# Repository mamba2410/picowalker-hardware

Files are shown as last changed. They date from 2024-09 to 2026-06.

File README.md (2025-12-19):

# picowalker hardware

This is the PCB hardware side of the [picowalker](https://github.com/mamba2410/picowalker) project.
The goal of the picowalker project is to create a new, modern equivalent to the Pokewalker distributed with the Pokemon HeartGold and SoulSilver games back in 2010.
Since those units are no longer sold and are getting harder and harder to obtain, creating a new version sounds like the easiest option. And the most fun.

The hardware is designed around the RP2350 chip. STM32U5 versions have been considered for longer battery life, but they're more expensive and I'm worried about availability (and the name "picowalker" wouldn't work!)

Software for this can be found in the [picowalker](https://github.com/mamba2410/picowalker/) and [picowalker-core](https://github.com/mamba2410/picowalker-core/) repos.

## Features

- RP2350A as the main microcontroller.
- 1.8" AMOLED screen DO0180FMST03, 448x368 resolution (running at 384x256 for 4x upscaling) driven by PIO'd QSPI (output only).
- Rechargeable lithum battery via USB-C using the BQ25628E PMIC.
- Larger form factor to accommodate larger screen and battery.
- Custom shell based on the original Pokewalker designed by Kamp.
- IrDA driven by PIO courtesy of Dmitry gr's PIO code.
- 64kB EEPROM using the M95512 chip (same as in the original walker).
- Code and extra image flash using 16MB W25Q128.
- Accelerometer with BMA400 (successor to the original Pokewalker's one).
- USB 1.1 connection for flexible communications.
- High accuracy, low power 32.768 kHz clock for more accurate timekeeping (100 PPM).

## Dependencies

- [KiCad](https://www.kicad.org/) V9.0+
- [KiKit](https://yaqwsx.github.io/KiKit/latest/installation/intro/) plugin to generate panels.
- Symbols, footprints and models are either in KiCad standard library or in a project library.

## Current state (updated 2025-12-19)

V0.4 has passed DRC checks. Will go through a few reviews so expect some tweaks.
Hoping that this will be the final version and, once validated, will be uplifted to V1.0.

Here's a render of the board.

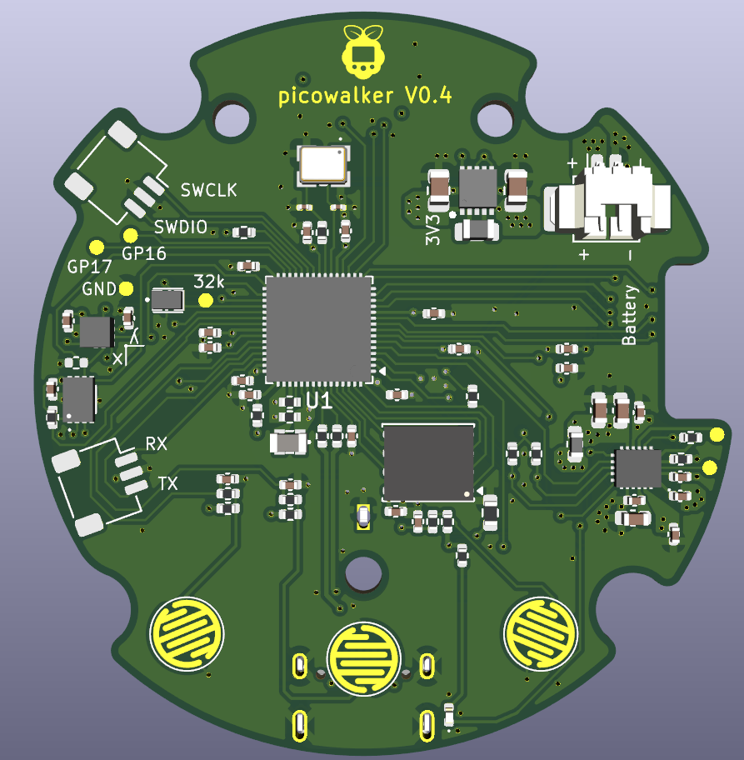
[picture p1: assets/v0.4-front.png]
front


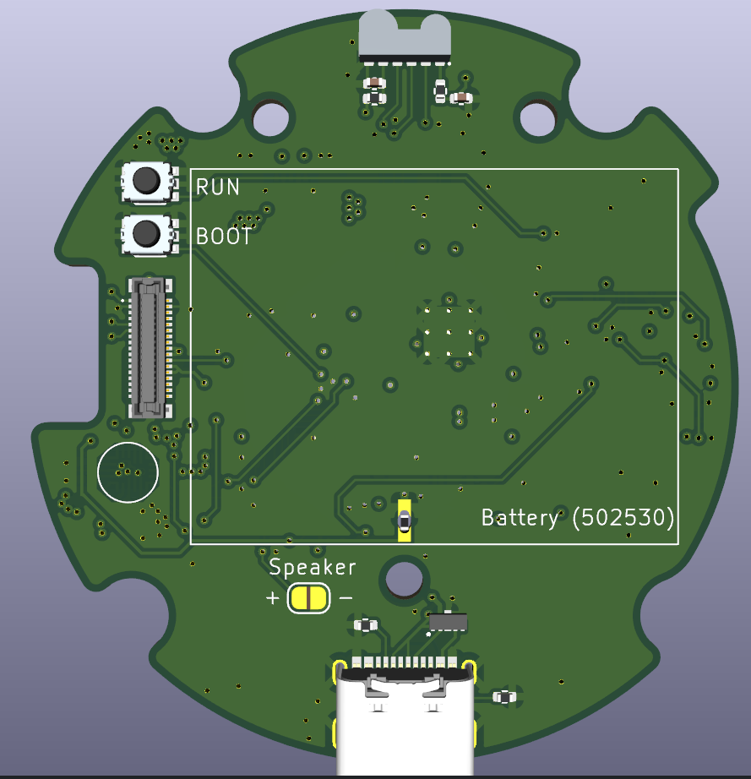
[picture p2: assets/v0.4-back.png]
back


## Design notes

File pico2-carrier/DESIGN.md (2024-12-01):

# Pico 2 Carrier board design

Already know that eeprom and accelerometer work.
Screen mostly works, but trying to eliminate interference by removing the jumper wires.

Heavily cutting unnecessary pins since we're very limited on the Pico 2 and preferably want to 
keep using the RP2350A version since the B version is physically much larger.

## Design goals

- Keep under the Pico 2 pin limit with minimal jumpers
- Separate battery and rest of board if charge circuit is bad
- Headers for screen in case the AXE534-127 connector is wired wrong
- Preferably 2-layer board but power management needs 4 layers
- Only single-sided components for ease of assembly

## Goals

On top of getting something working and broadly verifying 

- Generally verify schematics
- Get it portable
    - Reliable(?) step detection
- See if battery charging works
    - Needs lots of testing/verification (charge lim, values ok, EMI ok etc)
- Get screen more stable
- See if flash works
- See if PIO IrDA works
- Measure power consumption (from USB VBUS and battery/PMIC output)
    - Identify the most power-hungry things in the board
    - See how low rp2350 can go
    - See how low screen can go
- Check out power saving benefits
    - IrDA `IR_SD`
    - Screen `PWR_EN`
    - Putting things in sleep mode
    - Underclocking rp2350
- Identify pins that aren't strictly needed, so they can be cut in final version
    - `~{SCREEN_RST}` - software might be good enough
    - `~{BAT_CE}` - Software can disable charging even if this is asserted
    - `DBG_XX` - USB stdio works but these might be most useful
        (could disable transceiver and use IrDA pins as software-uart when not in connect mode)
- Using flash-as-eeprom
- Using pico as USB device

Things this WONT help out with

- Sound (had to cut that out because of pin space requirements)
- rp2350 power supply
- Converting VSYS to 3.3V
- Ditching separate flash for unified code/data flash
- USB-C connector, ESD protect and integration
- Fitting in form-factor/enclosure
    - And thermals

## Notes

### BQ25628E Battery charger PMIC

For the battery charging, The BQ25628E chip seems good and small enough to be used in the final version.
There is another chip in the line that's due to be out in the future that's smaller and cheaper 
but this one seems fine enough.

I'm trying to follow the reference design (what bits I can find in the datasheet) as closely as possible
since I'm not knowledgeable enough to deviate from it.
It might need a 4 layer board to have good grounding since there are a lot of crossing wires, especially
for the VBUS/VSYS and interface with the MCU.

### Passives

BQ25628E

- CVBUS 10V 1uF before derating
- CPMID 10V 10uF before derating
- CSYS 10V 20uF before derating
- CBAT 10V 10uF before derating
- LSW max 2.2uH
- CREGN 10V 4.7uF ceramic before derating
- CBTST 10B 47nF ceramic before derating
- Output capacitor 10V >=10uF ceramic X7R or X5R before derating
- Input capacitor (CPMID?) 25V 10uF ceramic X7R or X5R before derating

TFDU4101

- CVIRED rec. tantalum/fast rise 4.7uF/16V (assume before derating). Used as bulk/buffer
- CVCC rec. ceramic 0.1uF. Used in low-pass filter

M95512

- Decoupling capacitor between 10nF-100nF (assume before derating)

BMA400

- two decoupling capacitors 100nF (assume before derating)

W25Q128/IS25LP128

- No mention of capacitors

DO0180FMST08

- No mention of capacitors

## Datasheets and documentation

- Pico 2
    - [Pico 2 Datasheet](https://datasheets.raspberrypi.com/pico/pico-2-datasheet.pdf)
    - [RP2350 Datasheet](https://datasheets.raspberrypi.com/rp2350/rp2350-datasheet.pdf)
    - [RP2350 Hardware Design](https://datasheets.raspberrypi.com/rp2350/hardware-design-with-rp2350.pdf)
- M95512
    - [Datasheet](https://www.st.com/en/memories/m95512-w.html#documentation)
    - [Documentation](https://www.st.com/en/memories/m95512-w.html#documentation).
- BQ25628E
    - [Product Page](https://www.ti.com/product/BQ25628E)
    - [Datasheet](https://www.ti.com/lit/ds/symlink/bq25628e.pdf)
- W25Q128JV
    - [Product Page](https://www.winbond.com/hq/product/code-storage-flash-memory/serial-nor-flash/?__locale=en&partNo=W25Q128JV)
    - [Datasheet](https://www.mouser.com/datasheet/2/949/w25q128jv_revf_03272018_plus-1489608.pdf)
- BMA400
    - [Product Page](https://www.bosch-sensortec.com/products/motion-sensors/accelerometers/bma400/)
    - [Datasheet](https://www.bosch-sensortec.com/media/boschsensortec/downloads/datasheets/bst-bma400-ds000.pdf)
- TFDU4101
    - [Product Page](https://www.vishay.com/en/product/81288/)
    - [Datasheet](https://www.vishay.com/docs/81288/tfdu4101.pdf)
- DO0180FMST03
    - [Product Page (Module)](https://www.dwo.net.cn/pd.jsp?id=11924#_jcp=3_38)
    - [Product Page (Panel)](https://www.dwo.net.cn/pd.jsp?fromColId=2&id=11921#_pp=2_322)
    - [Module Datasheet](https://18746902.s21i.faimallusr.com/61/1/ABUIABA9GAAgivThrgYols7tsgE.pdf)
    - [Panel Datasheet](https://18746902.s21i.faimallusr.com/61/1/ABUIABA9GAAgm-3hrgYoq5PDogM.pdf)
    - [Driver Datasheet](https://18746902.s21i.faimallusr.com/61/1/ABUIABA9GAAgzvThrgYo8pyQBw.pdf)
    - [Touch Datasheet](https://18746902.s21i.faimallusr.com/61/1/ABUIABA9GAAg0-ThrgYosMjsrAY.pdf)

## Review

### EEPROM

According to ST's application note AN2014, the M95512 needs a (10k) pull-up on
the CSB line and strongly recommends a (100k) pull-down on the SCK line.
This then forces the SPI bus to be run in SPI mode 0.
It also strongly recommends a 100k pull-down on the D line (MOSI).
[Documentation](https://www.st.com/en/memories/m95512-w.html#documentation).

### PMIC

The PFET seemed to not work when OR'ing into the power circuit.
Removing it, then removing the Schottky diode on the pico, and shorting the
source and drain got the battery charging and power path to work.
Probably got the electrical design wrong since the pinouts seem correct.
But looking at the hardware design in the pico 2 datasheet, I have it correct.
Maybe the pull-down on VBUS is what's causing the PFET to work wrongly.

The SYS and PG signals seem to work well enough as LEDs.
Maybe don't need the PG signal, so can leave it floating, but no reason not to
have both.
No need to have them routed to the MCU since can read the status over I2C.

Battery charging works after the PFET situation was resolved.
Power-path also works.

ADC works, as well as interrupts, which is great.

### Flash

Haven't tested the flash, but that apparently also needs a 10k external pull-up
on the CS pin since that needs to follow VCC on power-up.

### IrDA

After some testing, the IR works well on PIO. Very glad I noticed the footprint
needed flipping since that was correct.
PIO needs to run quickly, works when clocked by 150MHz sys PLL, though not much
room for debug printing in between.

The current-limiting resistor hasn't seemed to have blown yet so I think it
seems to be fine with the power dissipation but should be a bit more careful.

Haven't tested the shutdown yet.

### Screen

The screen just works with the shorter traces, even running at 4x scale and
running from the 48MHz USB PLL.
Haven't tested max brightness yet but its probably similar to when on the
breadboard - can't run at panel max.
Screen flickers a lot less at 48MHz but that's the core code which needs to
manage it properly.
Also means that the connector is the correct polarity.

### Accel

Again, it just worked when porting the code over.
Polling for steps worked.
Some testing with interrupts and you can change the polarity and phase of the
interrupts.
Not gotten it to trigger yet, needs some more testing, but int is not really
needed.

### Power saving

Quick testing on the joulescope shows that there's some weirdness with going to
sleep.
First sleep from boot goes down to about 5mA, then subsequent sleeps go to 2mA.
1mA of the second was from the 3.3V rail, the rest was probably from the pico 2.
Good start, but not good enough.
This was without proper CS pull-ups on the flash chip.

Lots more testing to do:

- RP2350-E9
- Screen power saving

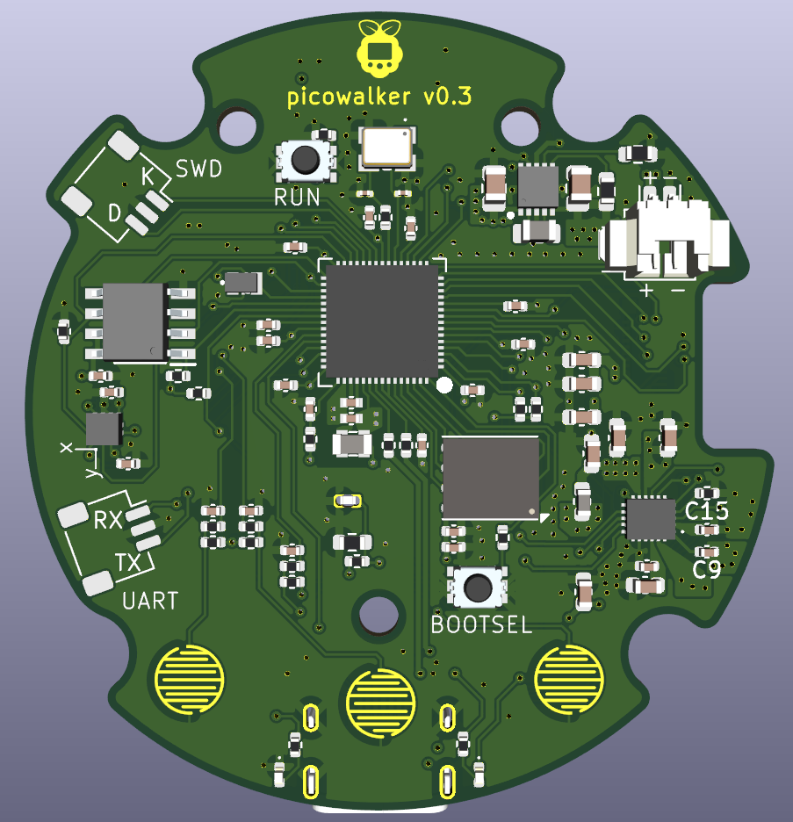
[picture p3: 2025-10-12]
assets/v0.3-front.png

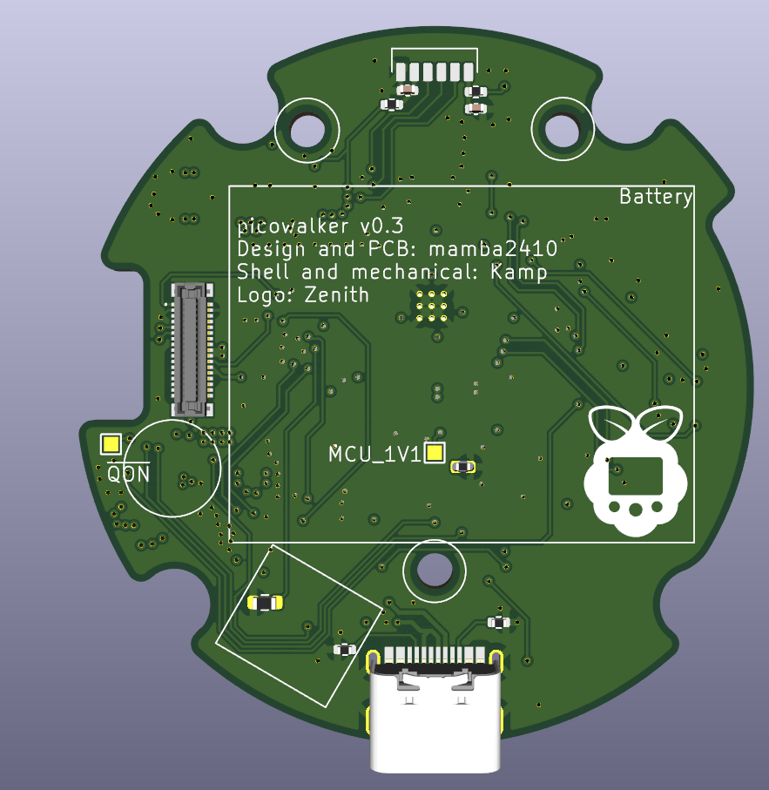
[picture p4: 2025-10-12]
assets/v0.3-back.png

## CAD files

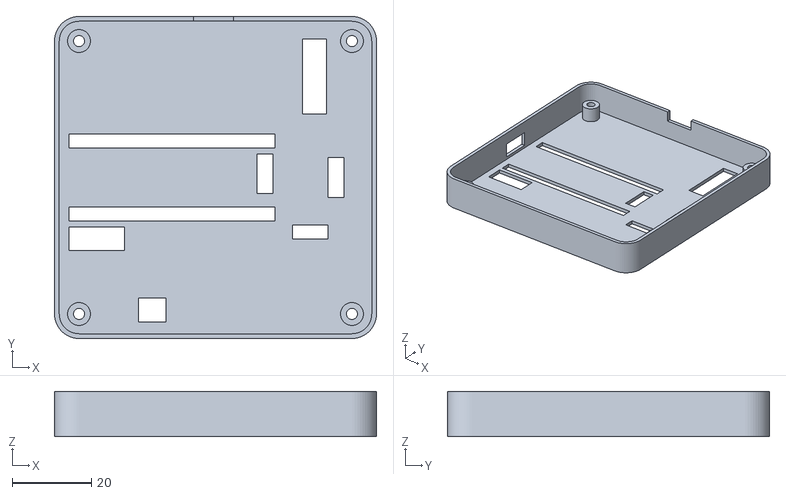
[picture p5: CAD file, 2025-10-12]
pico2-carrier/enclosure/shell-v0.0.1-bottom v12.stl
81.4 x 81.4 x 11.4

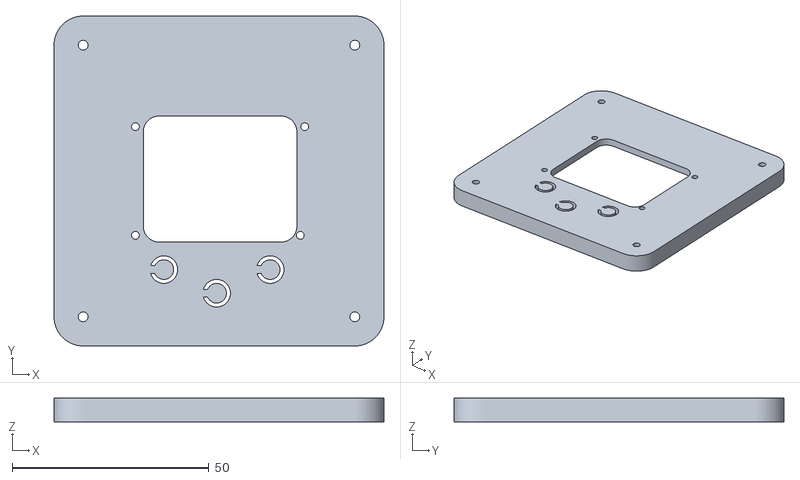
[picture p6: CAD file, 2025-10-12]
pico2-carrier/enclosure/shell-v0.0.1-top v5.stl
83.8 x 83.8 x 6.00

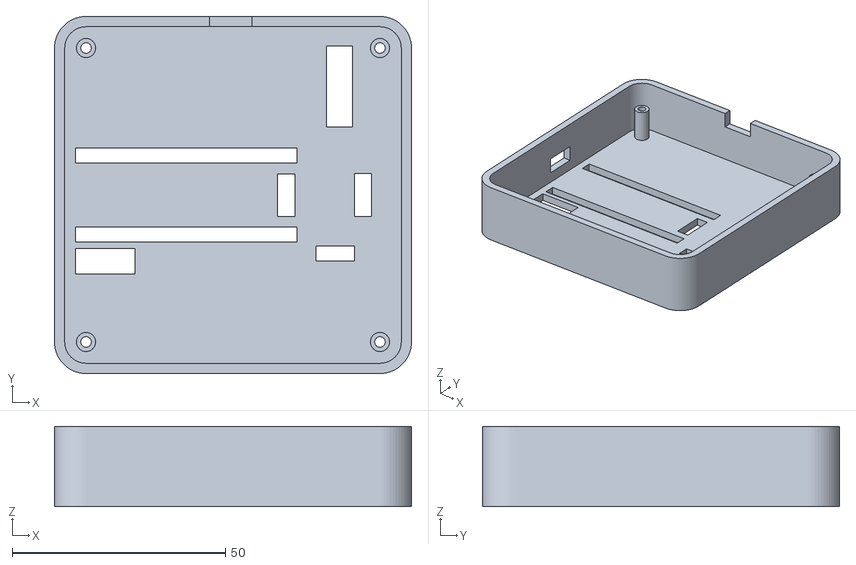
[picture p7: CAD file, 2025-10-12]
pico2-carrier/enclosure/shell-v0.0.1-bottom v4.stl
83.8 x 83.8 x 18.8

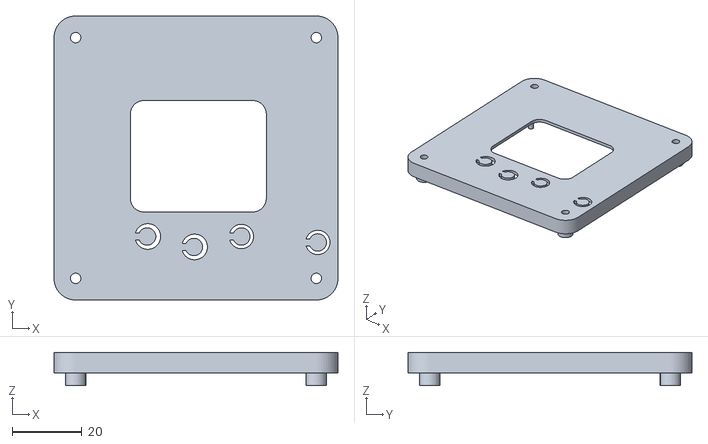
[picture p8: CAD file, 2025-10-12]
pico2-carrier/enclosure/shell-v0.0.1-top v12.stl
81.4 x 81.4 x 9.60

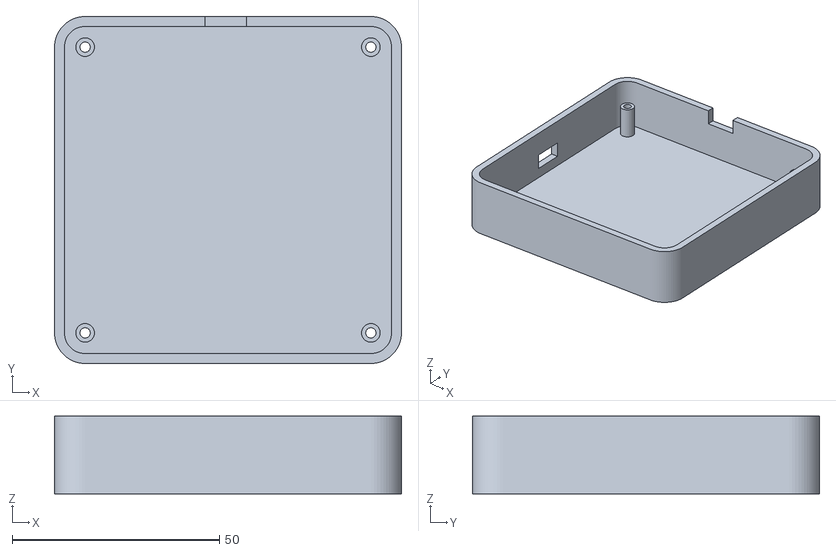
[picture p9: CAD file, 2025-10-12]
pico2-carrier/enclosure/shell-v0.0.1 v4.stl
83.8 x 83.8 x 18.8

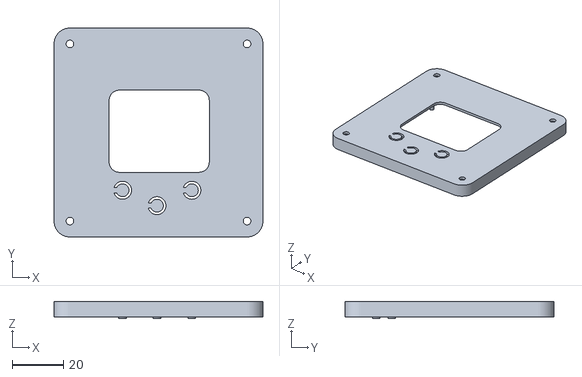
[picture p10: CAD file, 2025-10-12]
pico2-carrier/enclosure/shell-v0.0.1-top v7.stl
81.4 x 81.4 x 6.70

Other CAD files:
pico2-carrier/enclosure/shell-v0.0.1-bottom v7.stl
pico2-carrier/enclosure/shell-v0.0.1-bottom v8.stl
pico2-carrier/enclosure/shell-v0.0.1-top v4.stl
pico2-carrier/enclosure/shell-v0.0.1-top v8.stl

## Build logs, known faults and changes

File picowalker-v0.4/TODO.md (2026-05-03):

# Things to do before sending to fab

## Design

- Extend MP pads for debug headers

## Ordering

```bash
kikit panelize -p kikit.json picowalker-v0.4.kicad_pcb output/panelized/picowalker-v0.4-panelized.kicad_pcb
```

- 1.0 mm board thickness
- ENIG

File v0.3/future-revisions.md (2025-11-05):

# Things to do in a future revision

- Consolidate pull-ups to be a single value e.g. 10k or 5.1k, maybe also set ILIM to 5.1k for one less value.

## Second build

- Change USB connector to Amphenol version
- Replace 10k with 5.1k on button debounces
- Remove 0.1u cap from flash
- Try single 4.7u caps on screen VBAT and VDDIO
- Replace I2C pullups with 5.1k
- Replace accel decouples with 4.7u
- Remove eeprom SCL pulldown
- Replace eeprom CSB pullup with 5.1k
- Replace eeprom decouple with 4.7u
- Freestyle IrDA VCC2 filter to be 4.7u cap feeding into 47R resistor, to fix filter and consolidate parts
- Replace R18 and R19 pullups with 0R resistors to see if they actually need to be limiting anything
- Replace ILIM with 5.1k
- Replace battery and VBUS decoupling with 4.7u
- Replace top half of thermistor divider with 5.1k, and bottom with 30k
- Replace PG pull with 5.1k
- Replace R1 on rp2350 input filter with either 22R or 47R, probably 47R.
    - Datasheet and hardware design guide doesn't say much on the values.
      "33R and 4.7u is adequate" is about all thye say, and that its noise sensitive.
      47R and 4.7u is probably fine.

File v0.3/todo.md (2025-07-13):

# Todo before sending off for fab

## Parts

- Double check size of button contacts (currently 5mm diameter)
    - Contacts are 4.3mm, can't be arsed to change it this rev.
    - D-pad is also 4.3mm, letters are 5.3mm.

## Layout

- Move USB connector further out because its too recessed in the shell.
    - Currently already getting complained at by DRC.

## Checks

- DRC and make sure no nets are crossed due to the Big Move (TM).
- Assign and check part numbers and that they are in stock on mouser/partsbox
- Panelise
```
kikit panelize -p v0.3-kikit.json .\v0.3.kicad_pcb outputs\panelized\v0.3-panelized.kicad_pcb
```
- Export to JLC

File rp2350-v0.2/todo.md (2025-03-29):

# Todo before sending off for fab

Estimated shipping and fab is 8 days, so send off before weds 2nd april at latest.

Checks:

- [x] Doubile check pico 2 inductor
    - [x] footprint
    - [x] layout
- [x] Double check rp2350 xtal
    - [x] footprint
    - [x] layout
- [x] Double check rp2350
    - [x] footprint
    - [x] via hole size
- [x] Double check pmic
    - [x] layout
- [x] Double check screen
    - [x] power planes
    - [x] pinout
    - [x] qspi routing
    - [x] measure distance from screen centre to mezannine (28mm, will be too far left in v0.2 but that's fine as connector would be almost on the edge o (ignoring R&D costs)therwise)
- [x] USB C
    - [x] Footprint
    - [x] transmission lines
- [x] bootsel and run buttons
    - [x] make sure part number is correct
    - [x] footprint, 3d model doesn't sit on footprint, compare to datasheet
- [x] lposc xtal
    - [x] footptint
    - [ ] voltage - `DCC` means LVCMOS and rp2350 says cmos. Still don't know what CMOS vs LVCMOS means but both cover 3.3V so I think I'm fine.
- [x] 3v3 reg
    - [x] passive placement
    - [x] footprint
    - [x] inductor value - LBR2012T2R2M = 2.2uH, 0805 (2012) 260 mA max load, unshielded but not near any high-speed signals
- [x] irda
    - [x] footprint (pay attention to pins)
    - [x] passives location, filter etc.
- [x] uart and swd
    - [x] pin numbering
    - [x] check I have the right parts, both in stock and in spec - I actually have BM03* version which is top mount but I can squish the pins to make it side mount, probably.
- [x] battery connector
    - [x] compare to side-mount option and rotate to allow both orientations
- Assign and check part numbers and that they are in stock on mouser/partsbox
- Stitching vias
- Panelise
```
kikit panelize -p rp2350-v0.2-kikit.json .\rp2350-v0.2.kicad_pcb outputs\panelized\rp2350-v0.2-panelized.kicad_pcb
```
- Export to JLC

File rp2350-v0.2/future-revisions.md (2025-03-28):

# Things to do in a future revision

Smaller flash and eeprom packages

- W25Q128JVPIQ 6mm x 5mm WSON8 (£0.847 on mouser in 10 qty a/o 20250428)
- M95512-DFMC6TG 2mm x 3mm DFN8 (£0.634 on mouser in 10 qty a/o 20250428)

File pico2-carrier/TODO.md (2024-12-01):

# TODO - Hardware

## Improvements for v0.2

- M95512 chip needs hardware pull-up on CSB pin to ensure its high during power-on.
    - 10k seems fine

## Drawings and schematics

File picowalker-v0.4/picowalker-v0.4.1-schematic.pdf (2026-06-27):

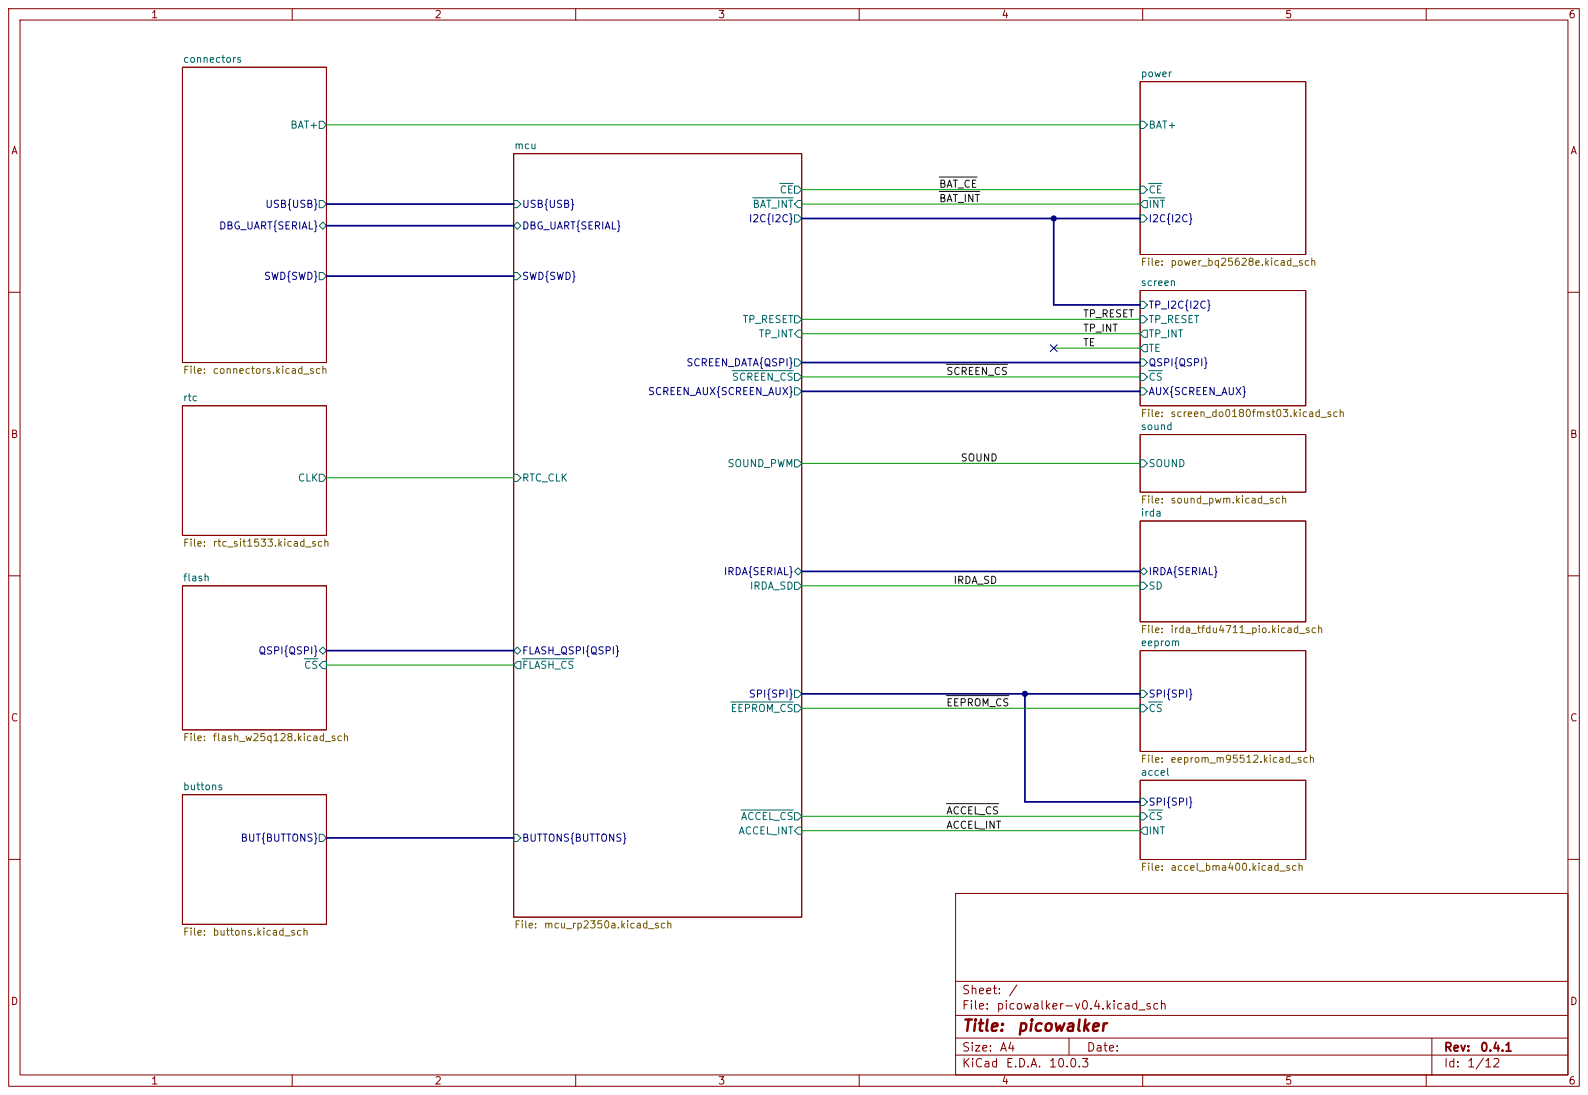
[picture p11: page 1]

SWD{SWD} connectors File: connectors.kicad_sch

File: mcu_rp2350a.kicad_sch CS QSPI{QSPI}

Size: A4 | Rev: 0.4.1
KiCad E.D.A. 10.0.3 | Id: 1/12

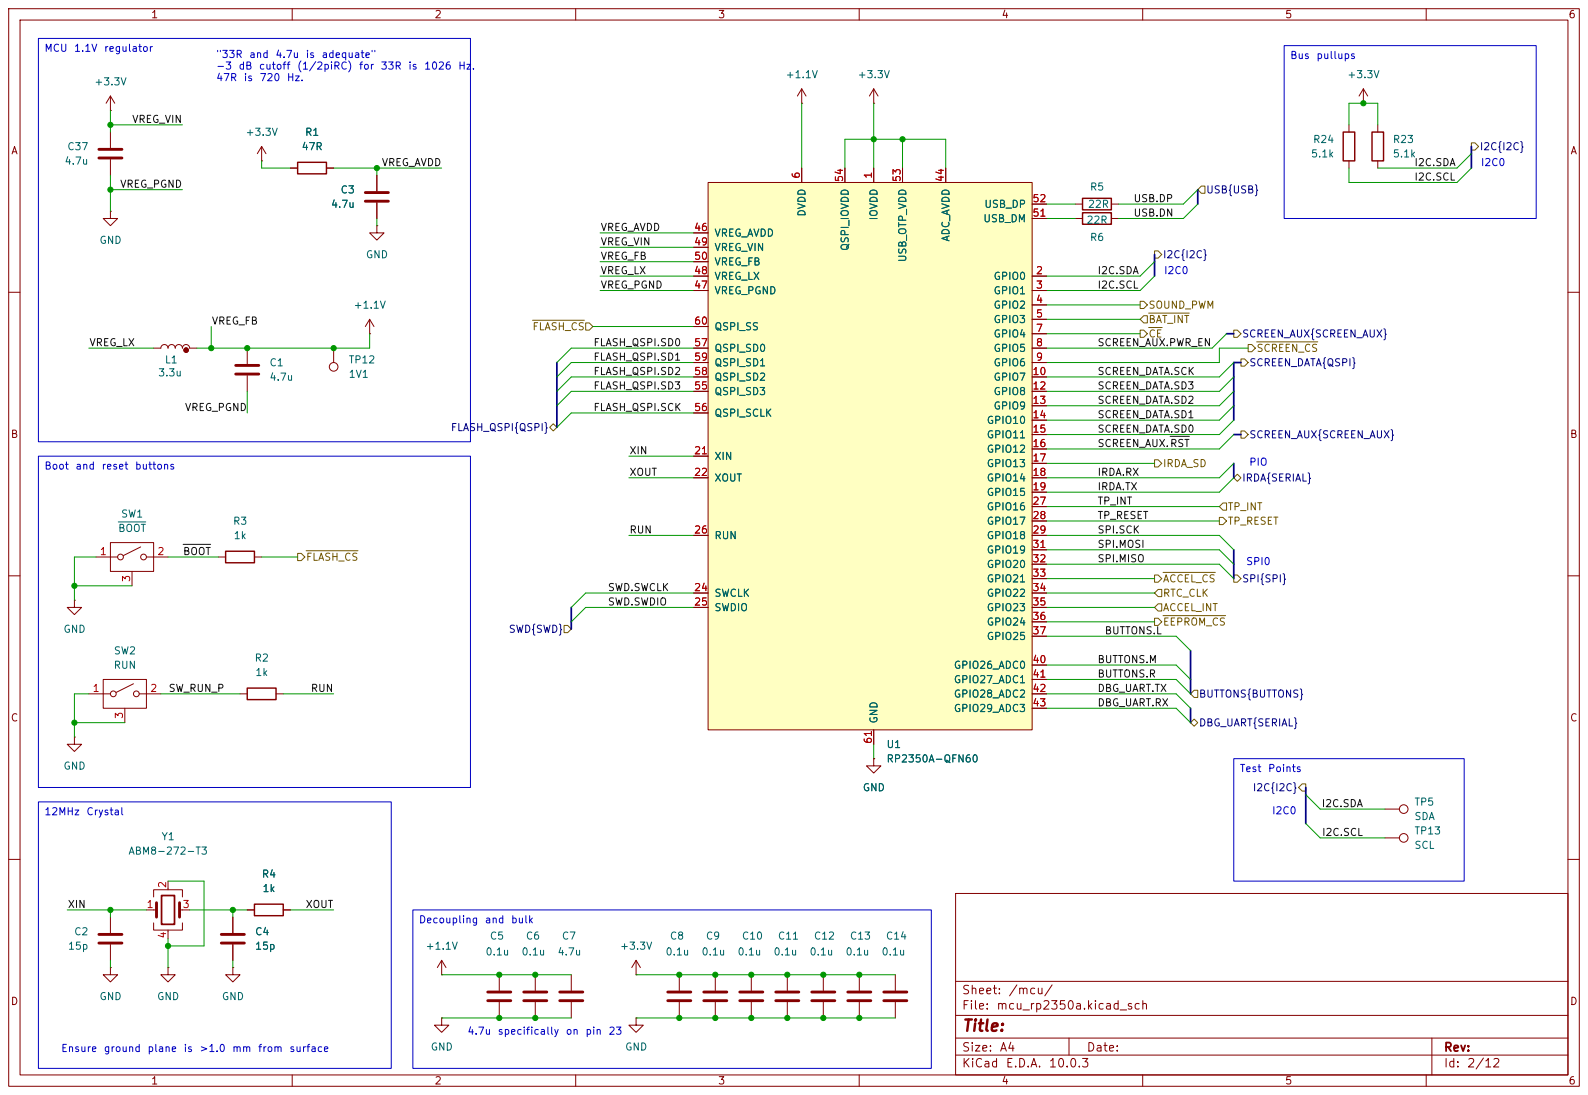
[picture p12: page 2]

"33R and 4.7u is adequate" -3 dB cutoff (1/2piRC) for 33R is 1026 Hz. 47R is 720 Hz.
22R GND 61 IOVDD

Ensure ground plane is >1.0 mm from surface

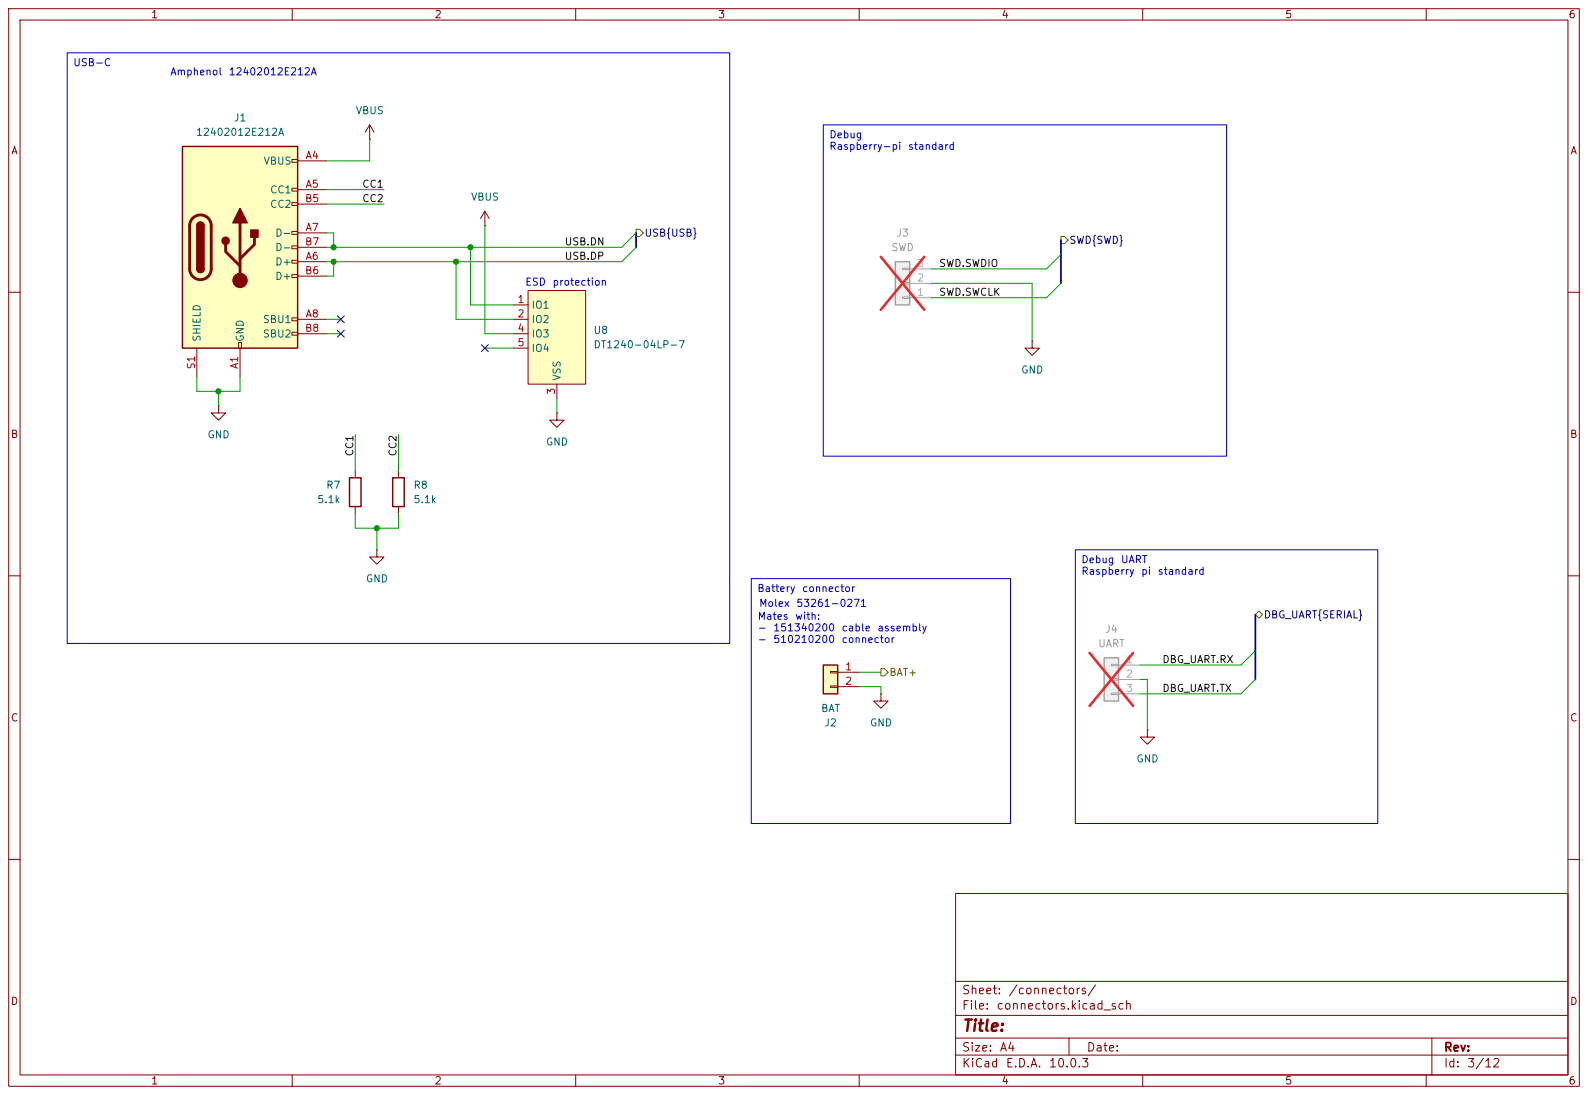
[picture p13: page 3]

Raspberry-pi standard USB-C

Debug UART Raspberry pi standard Debug

SWD.SWCLK USB.DN

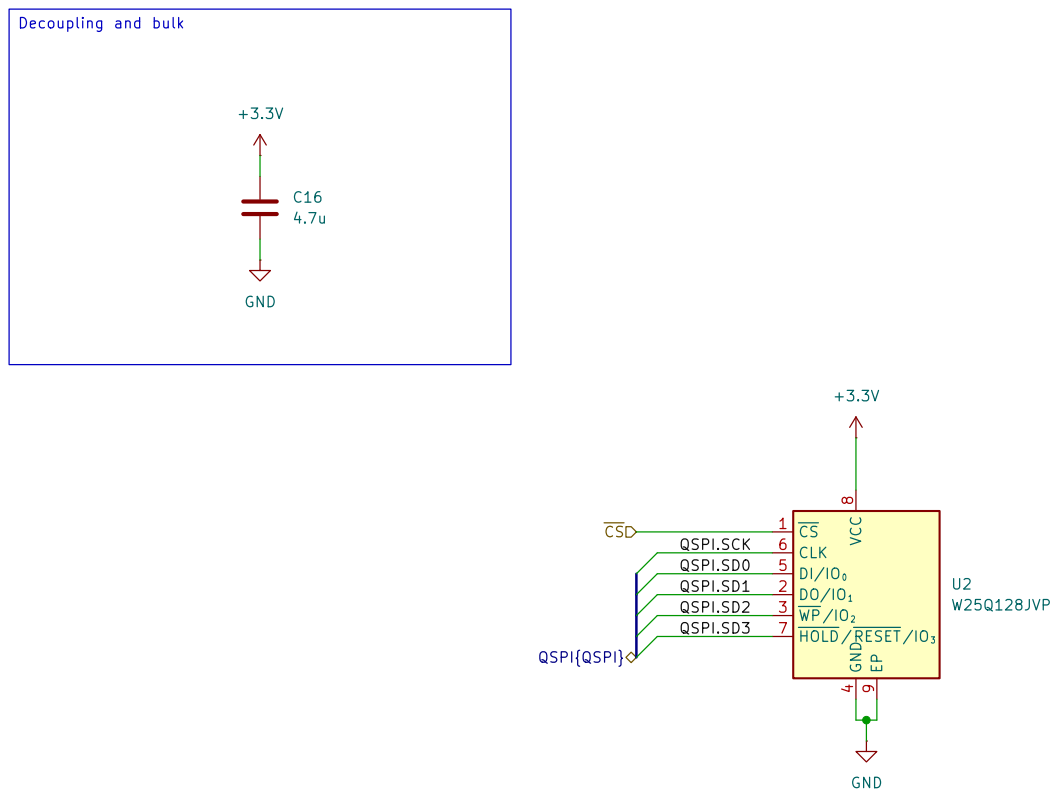
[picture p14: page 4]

4 DI/IO0 5 CLK 6 HOLD/RESET/IO3 7 VCC

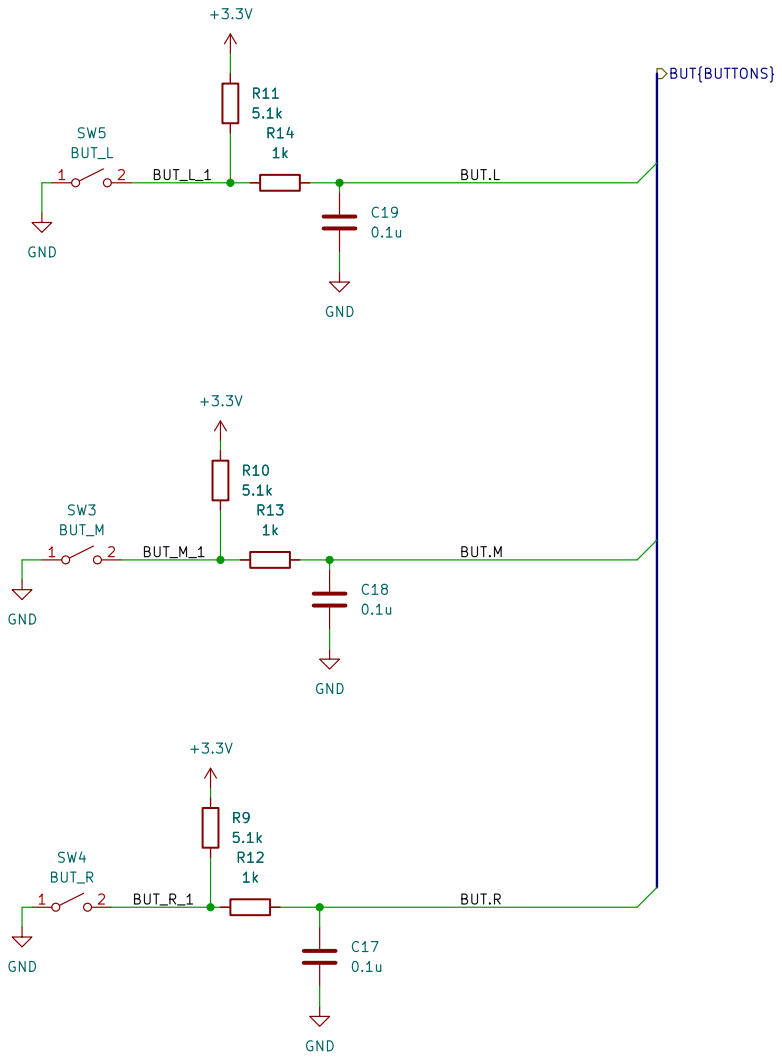
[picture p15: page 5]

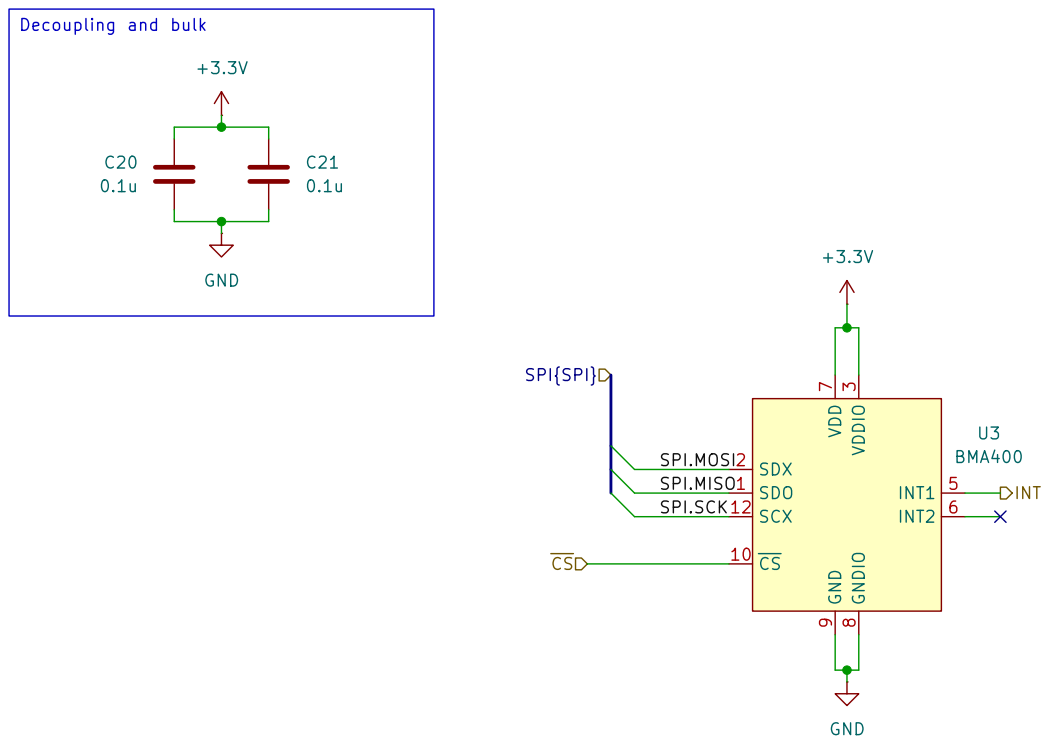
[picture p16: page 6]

SPI.MOSI Decoupling and bulk

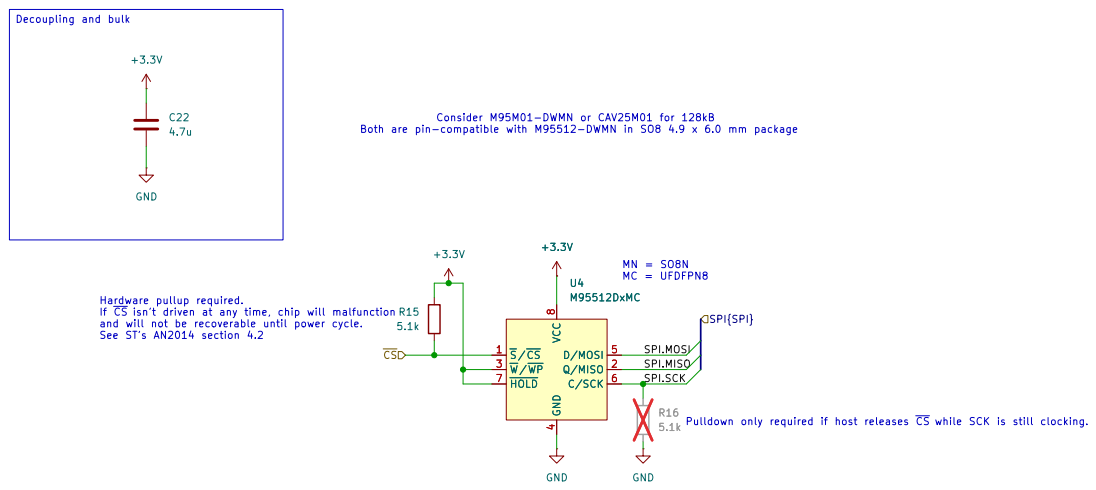
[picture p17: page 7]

Both are pin-compatible with M95512-DWMN in SO8 4.9 x 6.0 mm package Hardware pullup required.

If CS isn't driven at any time, chip will malfunction

4 D/MOSI 5 C/SCK 6 HOLD 7 VCC

SPI.MOSI SPI.SCK

AB

C

D

AB

C

### D Date:

## Title:

### File: irda_tfdu4711_pio.kicad_sch

### Sheet: /irda/

# GND VCC2

1

TXD 2 | RXD 3
SD 4 | VCC1

# 5 GND

6 U5
TFBS4711

IRDA{SERIAL}SD

IRDA.RX

IRDA.TX

VCC1

VCC2

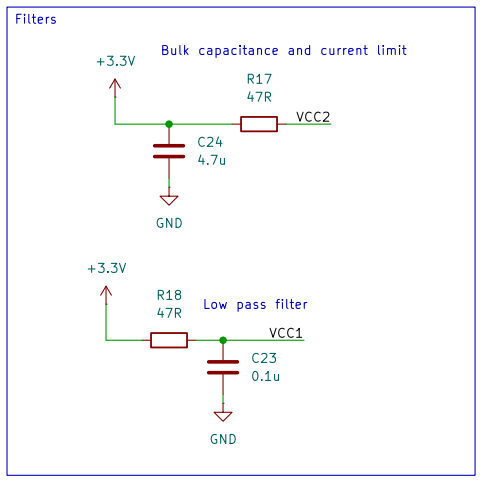
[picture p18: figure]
GND +3.3V +3.3V; 0.1u GND; VCC1; VCC2

Filters | Bulk capacitance and current limit From app note under "emitter signal timing"

"since the receiver saturates during transmission, it is also necessary to include a latency time of > 150 μs after transmission before the receiver is ready for reception again"

Original uses IrDA SIR V1.0 at 115200 baud, so we do the same. | Expect serial to be encoded with IrDA. MCU can do this with PIO or IrDA mode in UART Low pass filter | See Vishay's app note on reference layouts
https://www.vishay.com/docs/82610/referencelayoutscircuitdiagrams.pdf R17 is a current limiting resistor. 47R resistor gives IRED forward current of around 40-50 mA at 3.3 V. This is 132-150 mW, more than the common 1/16 W (62.5 mW) power rating for resistors. From testing, this seems to be fine since its pulsed.

Intensity is at around 15%. 100R resistor is 20 mA, or 66 mW, and <10% intensity. Datasheet says to expect <2 mA average current whtn I IRED (IRED forward current)

is 300 mA and a 20% duty cycle.

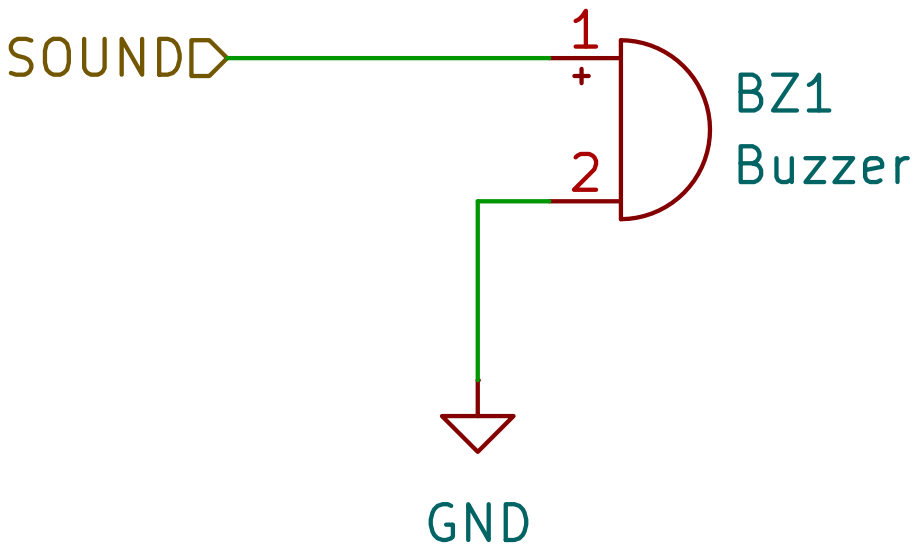
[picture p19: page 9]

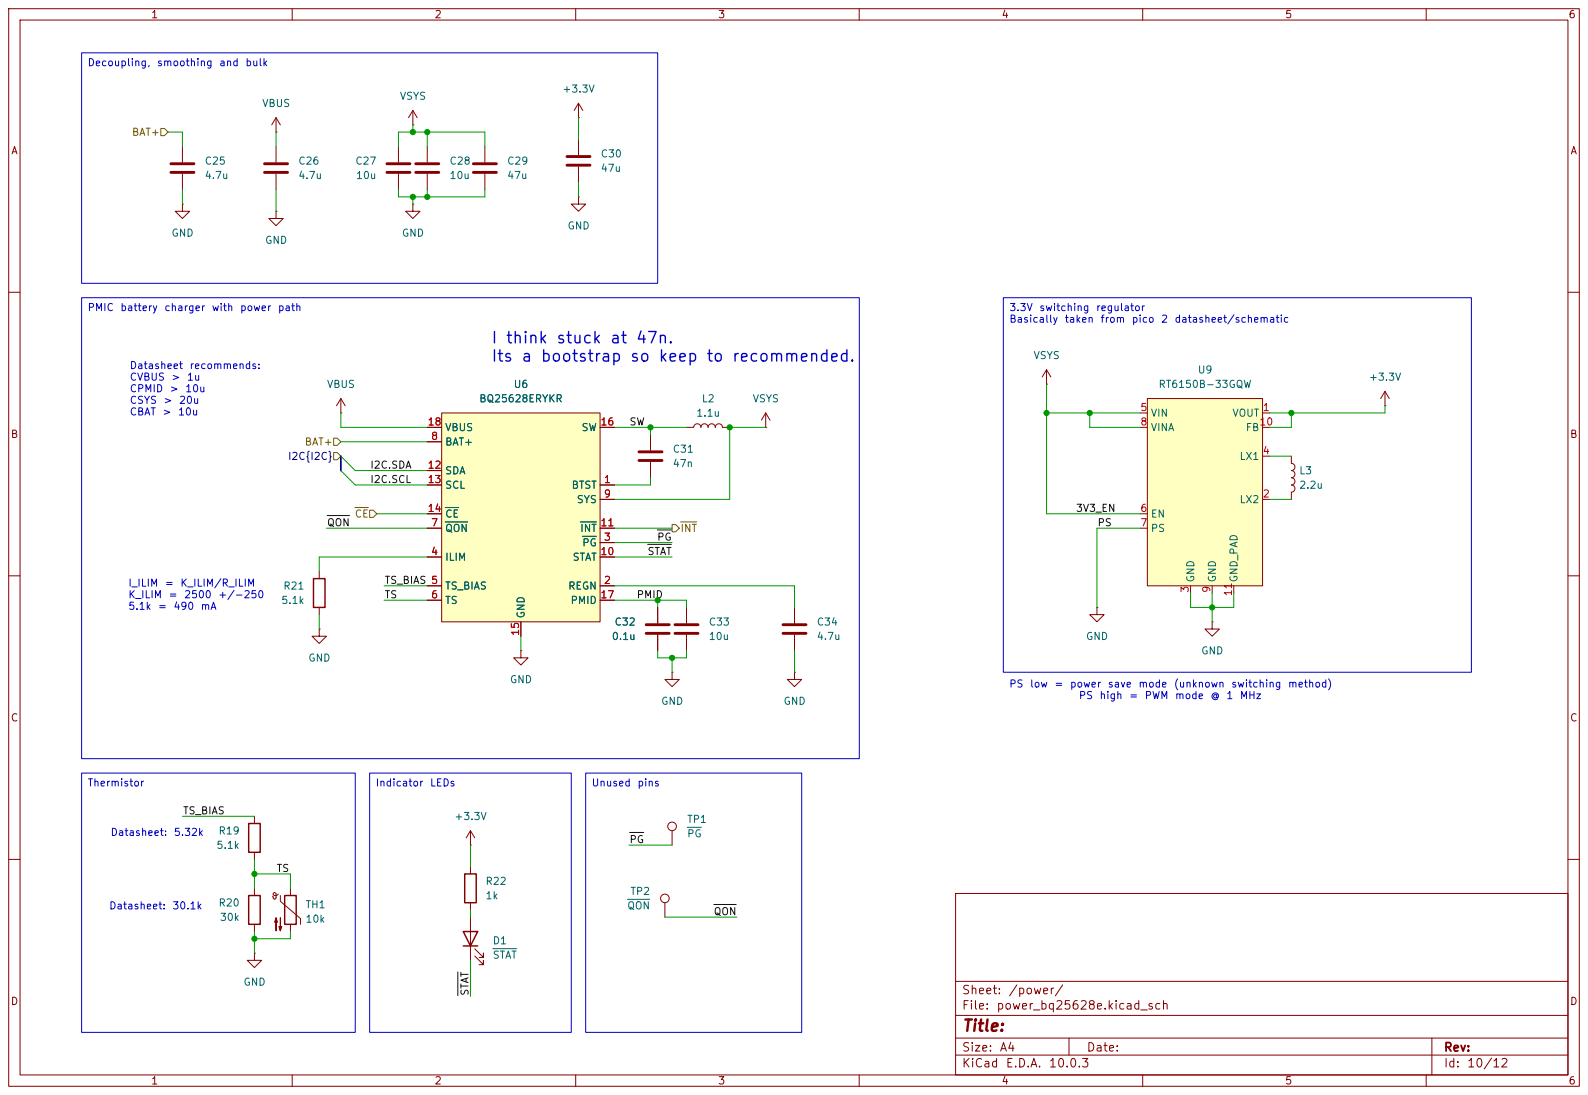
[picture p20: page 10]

Thermistor PMIC battery charger with power path

Basically taken from pico 2 datasheet/schematic
FB10 GND_PAD 11 U9 RT6150B-33GQW

I think stuck at 47n.
Its a bootstrap so keep to recommended.
SW 16 PMID 17

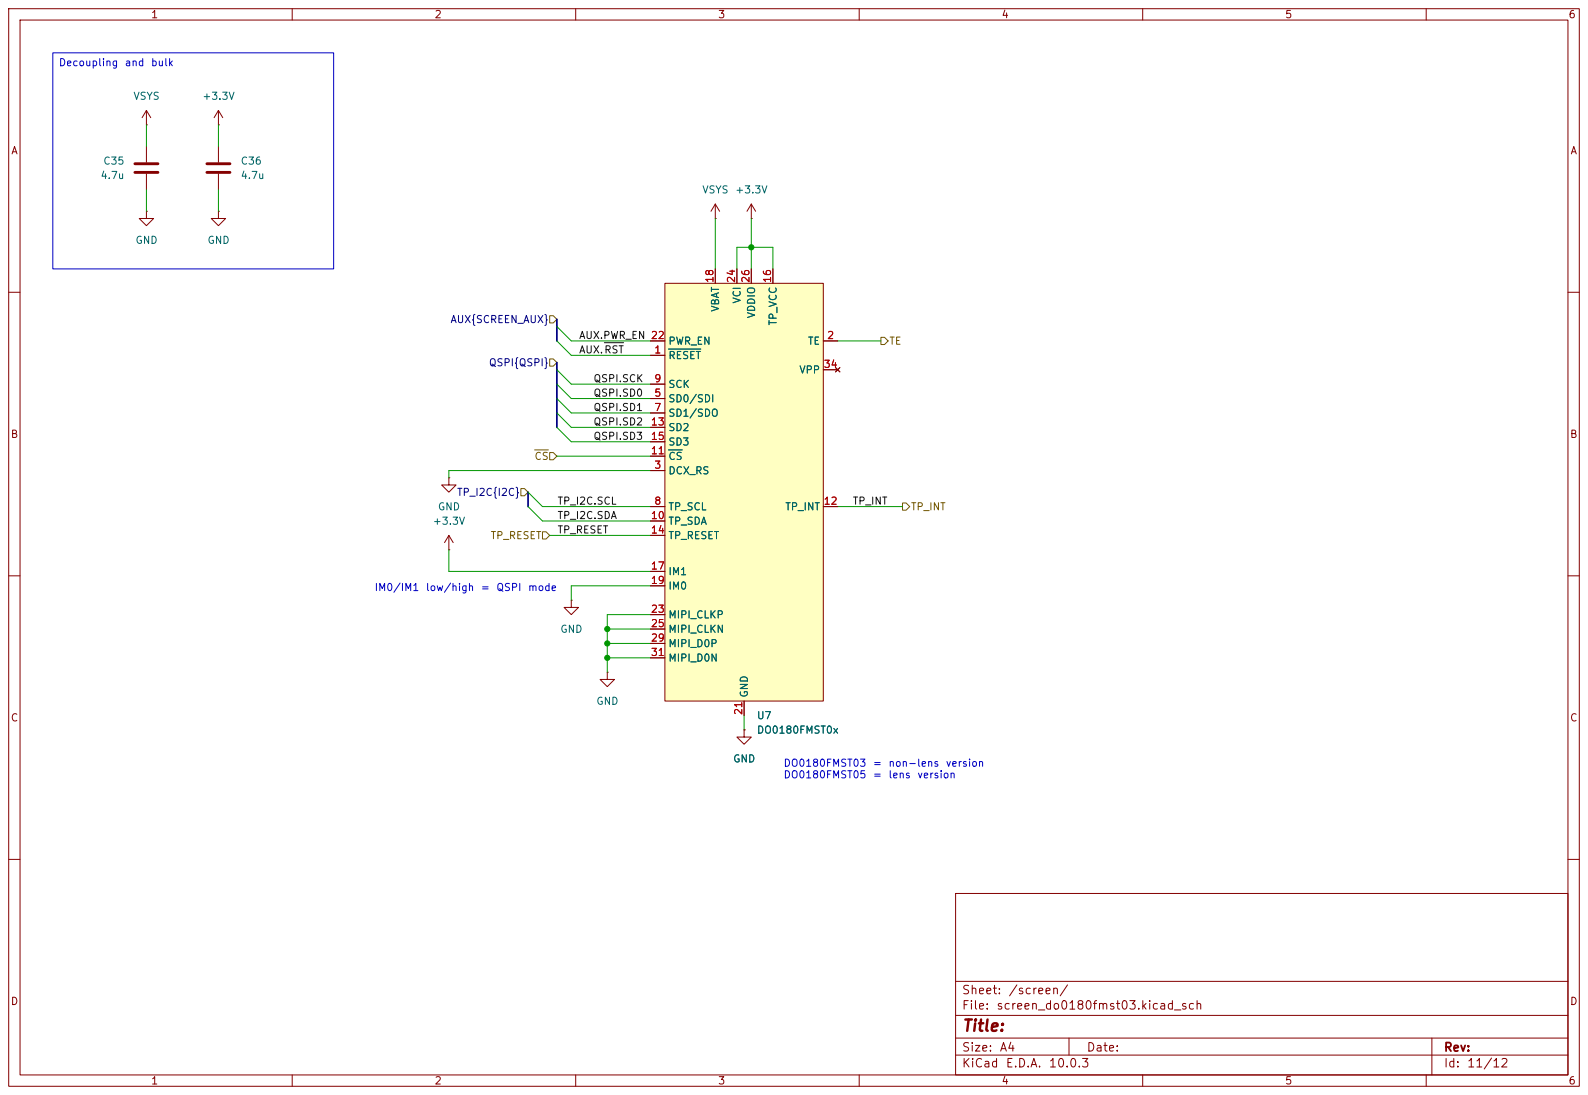
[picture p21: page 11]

TP_RESET QSPI.SD0 QSPI.SCK QSPI.SD3

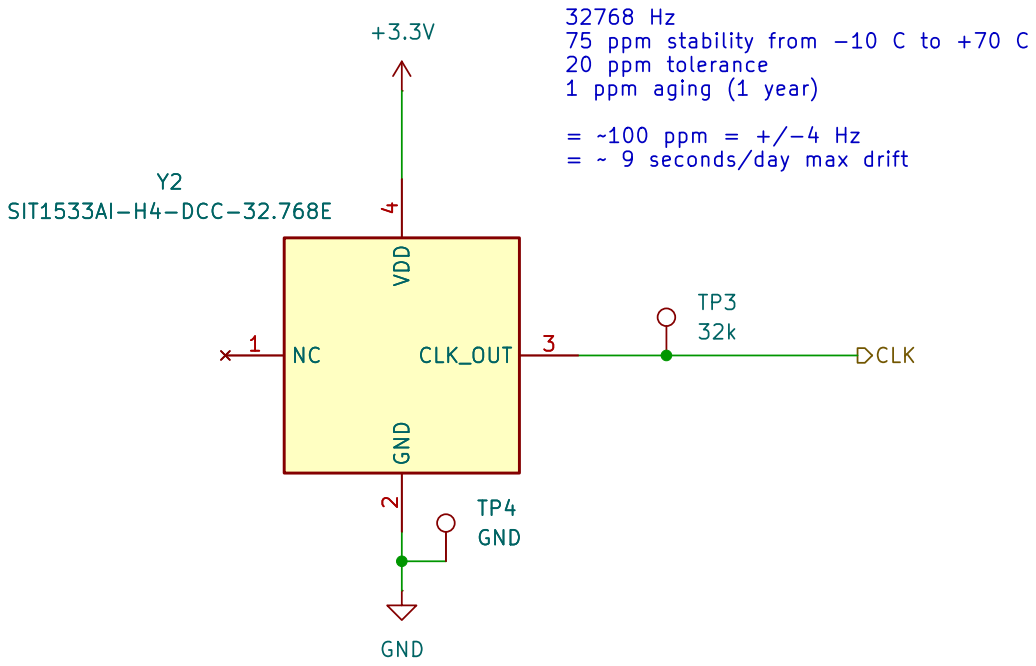
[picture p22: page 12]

32768 Hz 75 ppm stability from -10 C to +70 C

20 ppm tolerance 1 ppm aging (1 year) = ~100 ppm = +/-4 Hz = ~ 9 seconds/day max drift Y2

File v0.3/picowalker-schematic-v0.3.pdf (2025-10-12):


DBG_UART{TX,RX} connectors File: connectors.kicad_sch QSPI0{SS, SCLK, SD[0..3]}
USB{D+, D-} mcu File: mcu_rp2350a.kicad_sch

I2C{SDA, SCL} power File: power_smps.kicad_sch

SCREEN_AUX{~{CSB},PWR_EN, ~{RST}} screen File: screen_dw0180fmst08.kicad_sch SWD{SWDIO, SWCLK}

SWD{SWDIO, SWCLK} BAT+ USB{D+, D-}

IRDA{TX, RX, SD}

SPI{MOSI, MISO, SCK} eeprom

SPI{MOSI, MISO, SCK} accel File: accel_bma400.kicad_sch BUT{L, M, R} buttons File: buttons_debounce.kicad_sch

SPI{MISO, MOSI, SCK}


6 CSB 10 GND 9 GNDIO 8 VDD 7 AC1 BMA400 ACCEL_INT

Id: 2/11 Title: File: accel_bma400.kicad_sch Sheet: /accel/



6 QSPI_IOVDD 54 IOVDD 45 IOVDD 38 IOVDD 30 IOVDD 20 IOVDD 11 IOVDD

SPI0 TODO: Check if caps are the right value

SPI{MISO, MOSI, SCK}

Id: 4/11 Title: File: mcu_rp2350a.kicad_sch Sheet: /mcu/


Id: 5/11 Title: File: eeprom_m95512.kicad_sch Sheet: /eeprom/ GND


IRDA{TX, RX, SD}

Id: 6/11 Title: File: irda_pio.kicad_sch Sheet: /irda/


PMIC battery charger with power path

close to PMID/GND pins as possible

Battery decouple Ceramic! As close to

Id: 7/11 Title: File: power_smps.kicad_sch Sheet: /power/ GND


Id: 8/11 Title: File: connectors.kicad_sch Sheet: /connectors/ R1
5.1k GND


Id: 9/11 Title: File: sound_pwm.kicad_sch Sheet: /sound/


Release resistor Press resistor

Id: 11/11 Title: File: buttons_debounce.kicad_sch Sheet: /buttons/


4.7uF GND C39 0.1uFQSPI0{SS, SCLK, SD[0..3]} QSPI0.SD3 QSPI0.SD2 QSPI0.SD0 QSPI0.SD1 QSPI0.SCLK QSPI0.SS

Id: 12/11 Title: File: flash_w25q1282.kicad_sch Sheet: /flash/

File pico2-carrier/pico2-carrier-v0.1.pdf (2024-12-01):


6 VDD 7 GNDIO 8 GND 9 AC1 BMA400 GND

but I have TFDU4101 in stock Current lim = 60mA

+3.3V H3 MountingHole H4 MountingHole GND GND GND

screen-headers File: screen-headers.kicad_sch

Id: 1/4 Title: File: pico2-carrier.kicad_sch Sheet: / ~{SCREEN_RST} QSPI_SD0 ~{SCREEN_CSB} QSPI_SD1 QSPI_SD3 QSPI_SD2 QSPI_SCK


since screen will be behind a lens 00 = SPI 3-wire
01 = SPI 4-wire
+3.3V GND
0R GND

Id: 2/4 Title: File: screen-headers.kicad_sch Sheet: /screen-headers/


close to PMID/GND pins as possible

Id: 3/4 Title: File: battery-bq25628e.kicad_sch Sheet: /battery-bq25628e/


Id: 4/4 Title: File: buttons-debounce.kicad_sch Sheet: /buttons-debounce/ C19






















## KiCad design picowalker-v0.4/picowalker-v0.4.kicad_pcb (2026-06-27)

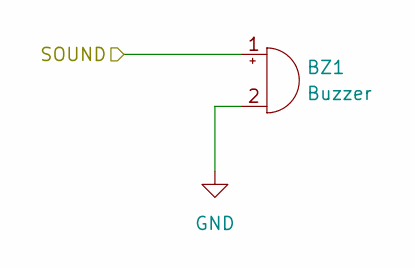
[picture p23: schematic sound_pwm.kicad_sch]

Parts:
BZ1: Buzzer; Huawei_P20_Speaker

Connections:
/SOUND: BZ1.1 (+); also elsewhere on the board
GND: BZ1.2 (-); also elsewhere on the board

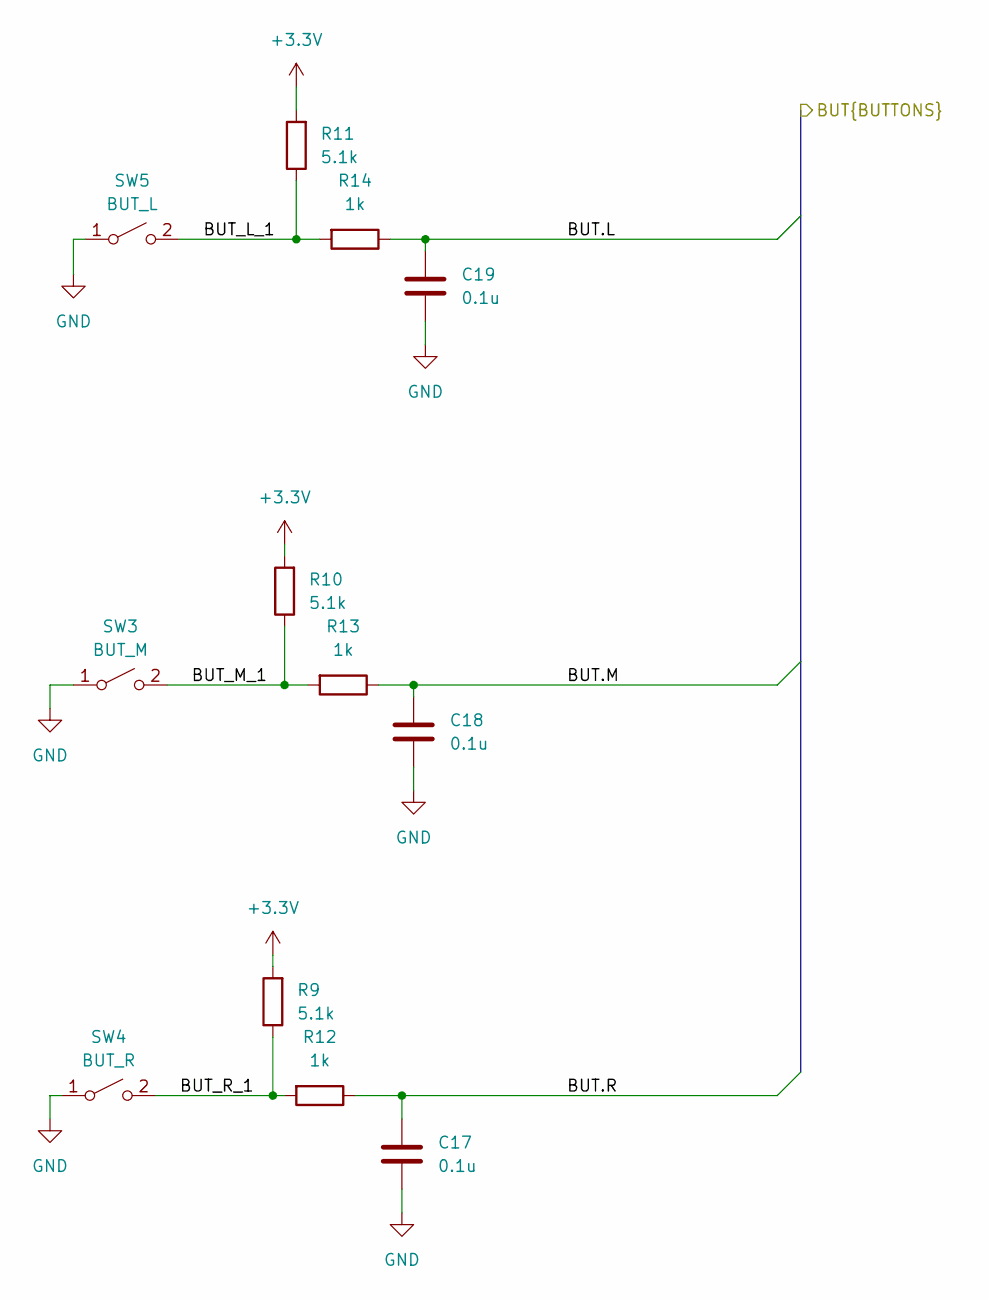
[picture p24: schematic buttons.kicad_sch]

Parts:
C17, C18, C19: 0.1u; C_0402_1005Metric
R9, R10, R11: 5.1k; R_0402_1005Metric
R12, R13, R14: 1k; R_0402_1005Metric
SW3: BUT_M; Button_membrane_4.2mm
SW4: BUT_R; Button_membrane_4.2mm
SW5: BUT_L; Button_membrane_4.2mm

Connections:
+3.3V: R9.2, R10.2, R11.2; also elsewhere on the board
/buttons/BUT.L: C19.1, R14.1; also elsewhere on the board
/buttons/BUT.M: C18.1, R13.1; also elsewhere on the board
/buttons/BUT.R: C17.1, R12.1; also elsewhere on the board
/buttons/BUT_L_1: R11.1, R14.2, SW5.2 (B)
/buttons/BUT_M_1: R10.1, R13.2, SW3.2 (B)
/buttons/BUT_R_1: R9.1, R12.2, SW4.2 (B)
GND: C17.2, C18.2, C19.2, SW3.1 (A), SW4.1 (A), SW5.1 (A); also elsewhere on the board

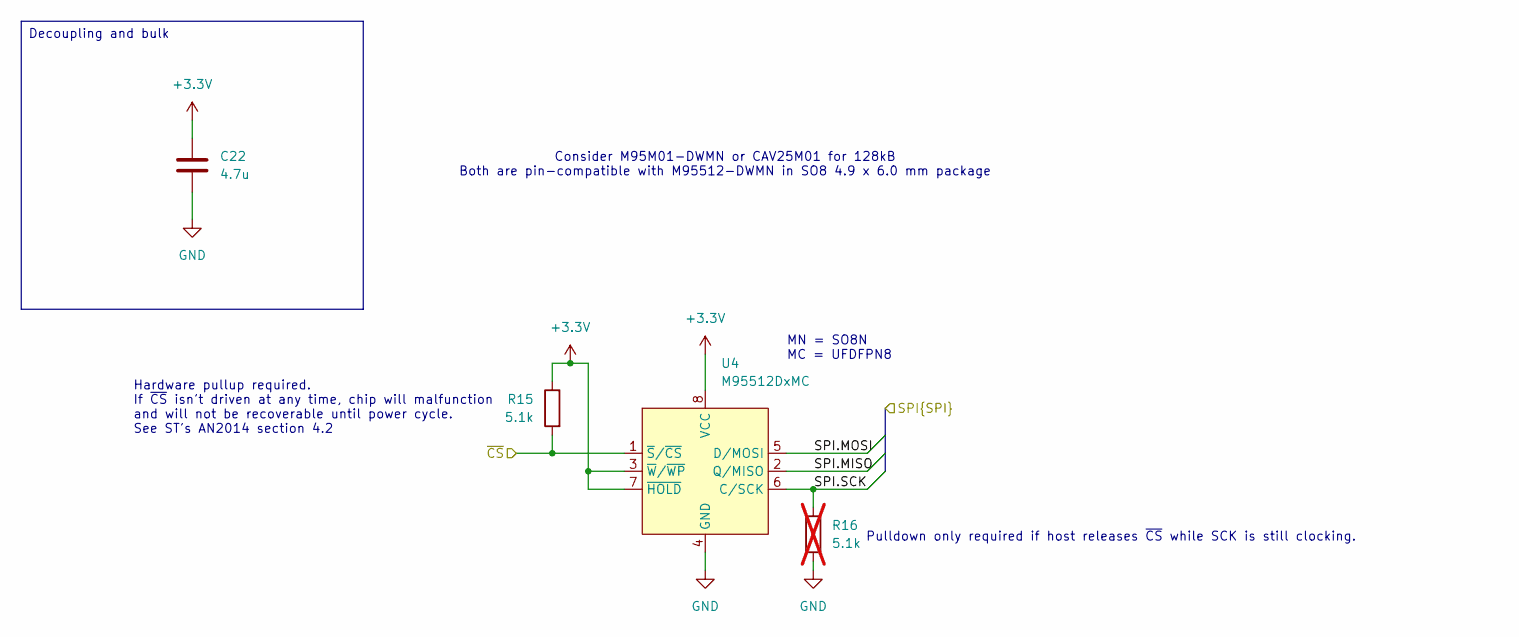
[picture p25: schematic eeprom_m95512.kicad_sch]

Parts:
C22: 4.7u; C_0402_1005Metric
R15: 5.1k; R_0402_1005Metric
R16: 5.1k; R_0402_1005Metric; not fitted
U4: M95512DxMC; UFDFPN8

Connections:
+3.3V: C22.1, R15.1, U4.3 (~W/~WP), U4.7 (~HOLD), U4.8 (VCC); also elsewhere on the board
/accel/SPI.MISO: U4.2 (Q/MISO); also elsewhere on the board
/accel/SPI.MOSI: U4.5 (D/MOSI); also elsewhere on the board
/accel/SPI.SCK: R16.1, U4.6 (C/SCK); also elsewhere on the board
/~EEPROM_CS: R15.2, U4.1 (~S/~CS); also elsewhere on the board
GND: C22.2, R16.2, U4.4 (GND), U4.9 (EPAD); also elsewhere on the board

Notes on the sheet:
MN = SO8N MC = UFDFPN8
Consider M95M01-DWMN or CAV25M01 for 128kB Both are pin-compatible with M95512-DWMN in SO8 4.9 x 6.0 mm package
Pulldown only required if host releases ~{CS} while SCK is still clocking.
Hardware pullup required. If ~{CS} isn't driven at any time, chip will malfunction and will not be recoverable until power cycle. See ST's AN2014 section 4.2
Decoupling and bulk

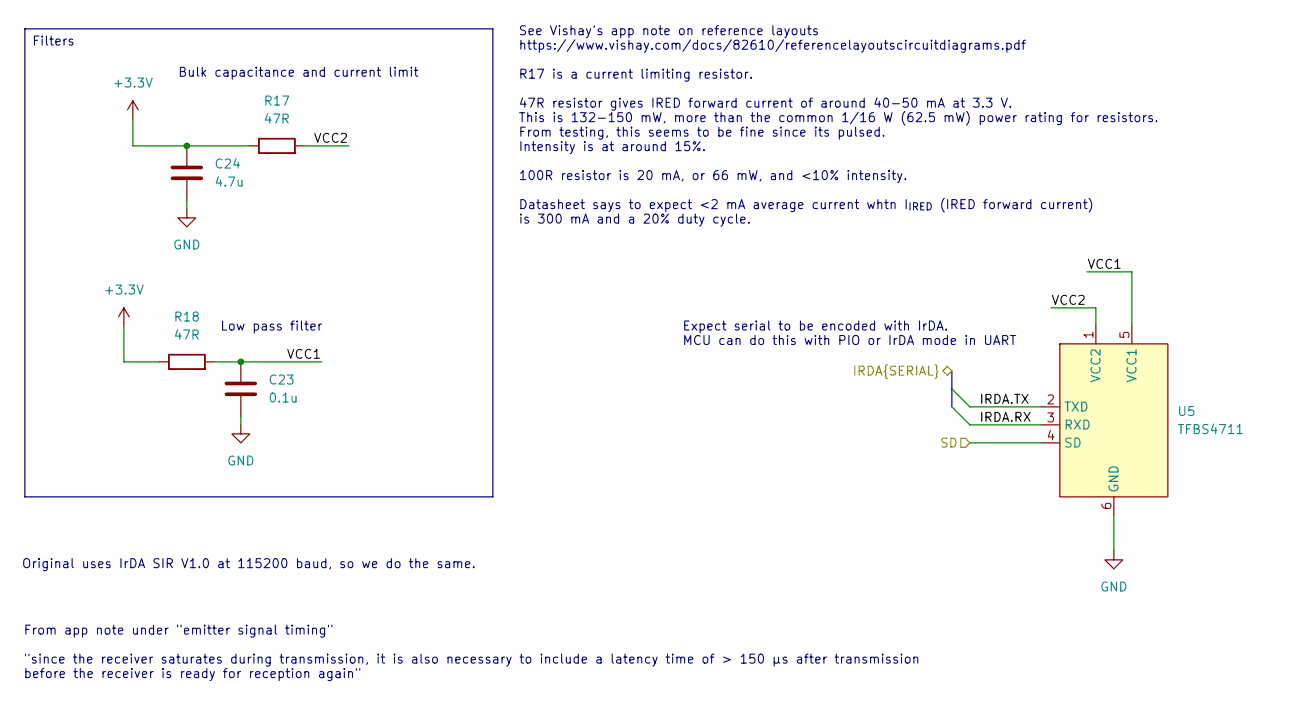
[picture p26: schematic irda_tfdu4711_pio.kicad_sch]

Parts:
C23: 0.1u; C_0402_1005Metric
C24: 4.7u; C_0402_1005Metric
R17, R18: 47R; R_0402_1005Metric
U5: TFBS4711; TFBS4711-TR

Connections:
+3.3V: C24.1, R17.1, R18.1; also elsewhere on the board
/IRDA_SD: U5.4 (SD); also elsewhere on the board
/irda/IRDA.RX: U5.3 (RXD); also elsewhere on the board
/irda/IRDA.TX: U5.2 (TXD); also elsewhere on the board
/irda/VCC1: C23.1, R18.2, U5.5 (VCC1)
/irda/VCC2: R17.2, U5.1 (VCC2)
GND: C23.2, C24.2, U5.6 (GND); also elsewhere on the board

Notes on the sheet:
Original uses IrDA SIR V1.0 at 115200 baud, so we do the same.
Expect serial to be encoded with IrDA. MCU can do this with PIO or IrDA mode in UART
Bulk capacitance and current limit
See Vishay's app note on reference layouts https://www.vishay.com/docs/82610/referencelayoutscircuitdiagrams.pdf R17 is a current limiting resistor. 47R resistor gives IRED forward current of around 40-50 mA at 3.3 V. This is 132-150 mW, more than the common 1/16 W (62.5 mW) power rating for resist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
From app note under "emitter signal timing" "since the receiver saturates during transmission, it is also necessary to include a latency time of > 150 μs after transmission before the receiver is ready for reception again"
Low pass filter
Filters

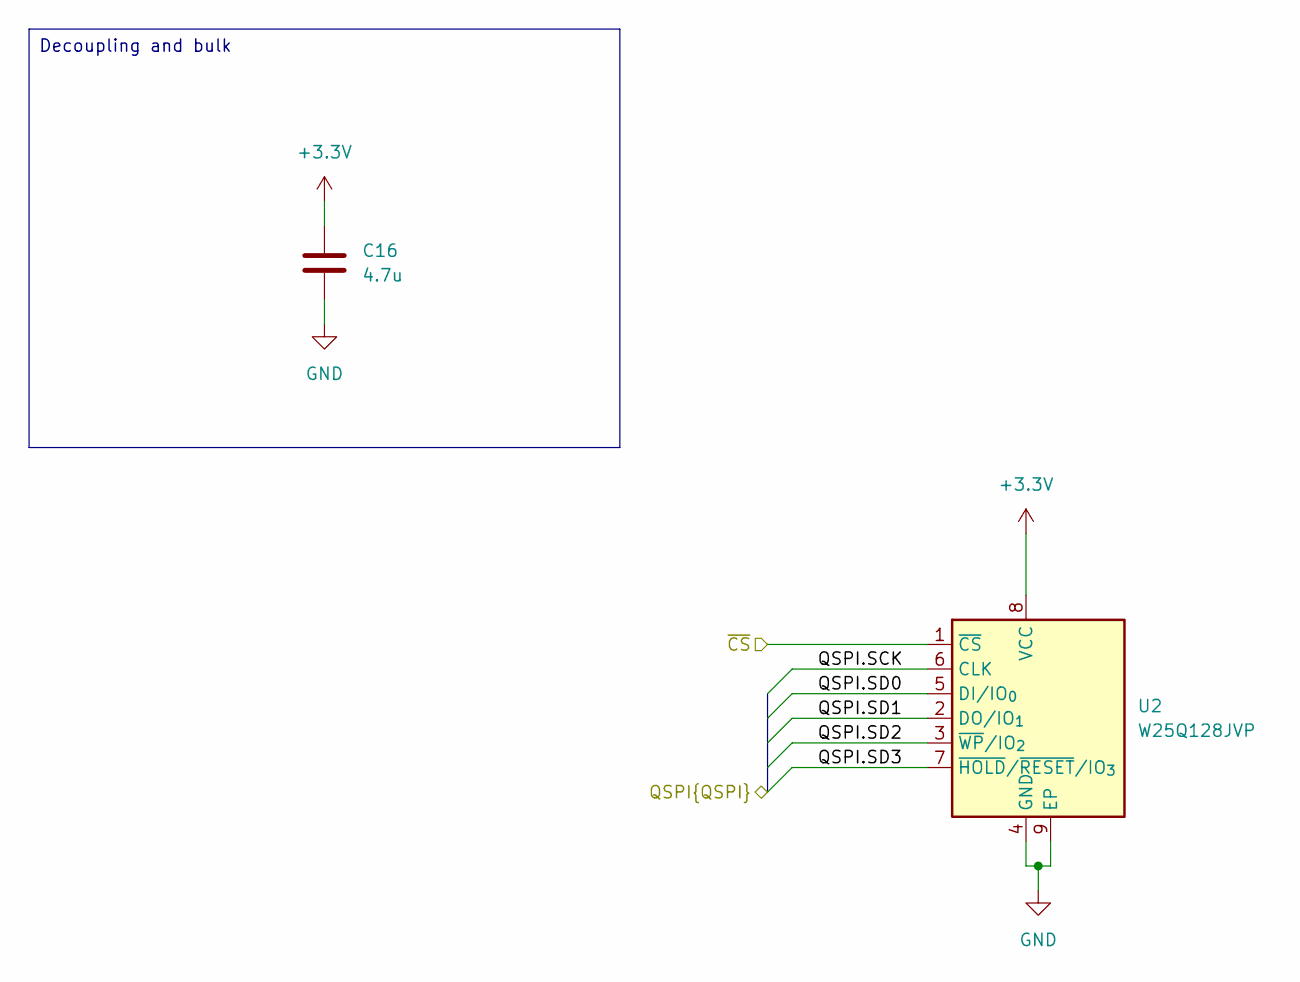
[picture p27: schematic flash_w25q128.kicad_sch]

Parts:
C16: 4.7u; C_0402_1005Metric
U2: W25Q128JVP; WSON-8-1EP_6x5mm_P1.27mm_EP3.4x4.3mm

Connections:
+3.3V: C16.1, U2.8 (VCC); also elsewhere on the board
/flash/QSPI.SCK: U2.6 (CLK); also elsewhere on the board
/flash/QSPI.SD0: U2.5 (DI/IO_{0}); also elsewhere on the board
/flash/QSPI.SD1: U2.2 (DO/IO_{1}); also elsewhere on the board
/flash/QSPI.SD2: U2.3 (~WP/IO_{2}); also elsewhere on the board
/flash/QSPI.SD3: U2.7 (~HOLD/~RESET/IO_{3}); also elsewhere on the board
/flash/~CS: U2.1 (~CS); also elsewhere on the board
GND: C16.2, U2.4 (GND), U2.9 (EP); also elsewhere on the board

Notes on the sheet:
Decoupling and bulk

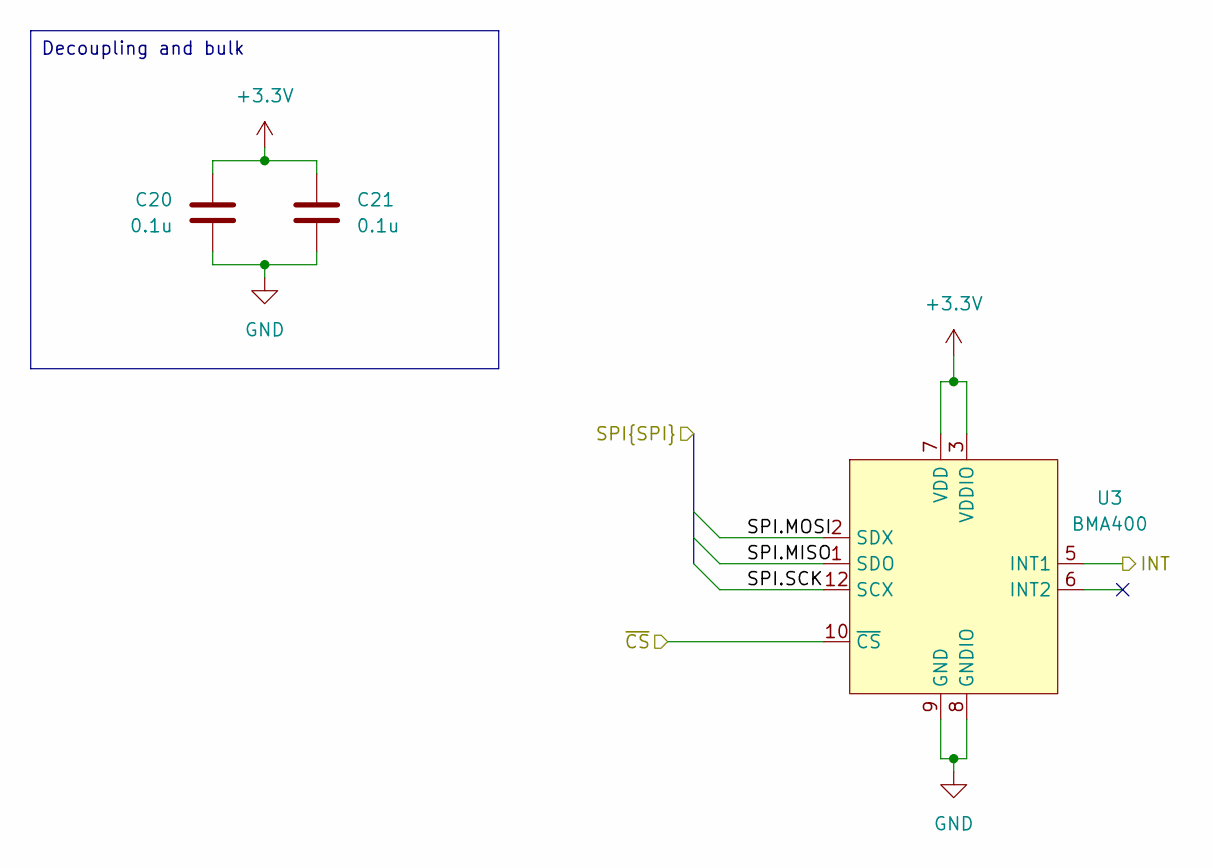
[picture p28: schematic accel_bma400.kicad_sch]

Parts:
C20, C21: 0.1u; C_0402_1005Metric
U3: BMA400; BOSCH_LGA-12_BMA400

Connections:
+3.3V: C20.1, C21.1, U3.3 (VDDIO), U3.7 (VDD); also elsewhere on the board
/ACCEL_INT: U3.5 (INT1); also elsewhere on the board
/accel/SPI.MISO: U3.1 (SDO); also elsewhere on the board
/accel/SPI.MOSI: U3.2 (SDX); also elsewhere on the board
/accel/SPI.SCK: U3.12 (SCX); also elsewhere on the board
/~ACCEL_CS: U3.10 (~CS); also elsewhere on the board
GND: C20.2, C21.2, U3.8 (GNDIO), U3.9 (GND); also elsewhere on the board

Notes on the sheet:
Decoupling and bulk

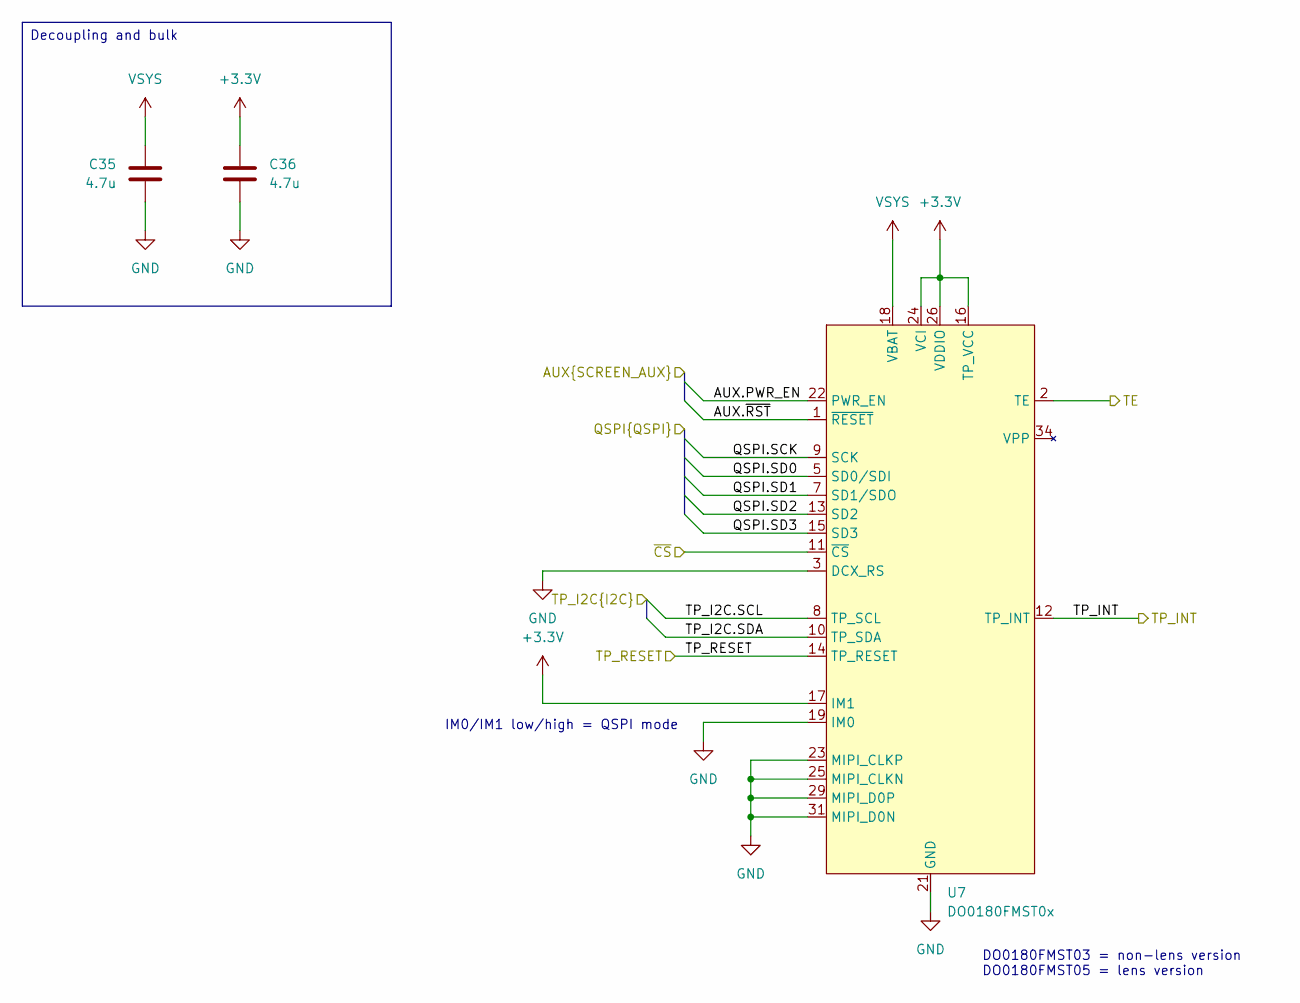
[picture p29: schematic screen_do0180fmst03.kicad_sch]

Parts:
C35, C36: 4.7u; C_0402_1005Metric
U7: DO0180FMST0x; AXE534127

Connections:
+3.3V: C36.2, U7.16 (TP_VCC), U7.17 (IM1), U7.24 (VCI), U7.26 (VDDIO); also elsewhere on the board
/TE: U7.2 (TE)
/TP_INT: U7.12 (TP_INT); also elsewhere on the board
/TP_RESET: U7.14 (TP_RESET); also elsewhere on the board
/mcu/I2C.SCL: U7.8 (TP_SCL); also elsewhere on the board
/mcu/I2C.SDA: U7.10 (TP_SDA); also elsewhere on the board
/mcu/SCREEN_AUX.PWR_EN: U7.22 (PWR_EN); also elsewhere on the board
/mcu/SCREEN_AUX.~RST: U7.1 (~RESET); also elsewhere on the board
/mcu/SCREEN_DATA.SCK: U7.9 (SCK); also elsewhere on the board
/mcu/SCREEN_DATA.SD0: U7.5 (SD0/SDI); also elsewhere on the board
/mcu/SCREEN_DATA.SD1: U7.7 (SD1/SDO); also elsewhere on the board
/mcu/SCREEN_DATA.SD2: U7.13 (SD2); also elsewhere on the board
/mcu/SCREEN_DATA.SD3: U7.15 (SD3); also elsewhere on the board
/~SCREEN_CS: U7.11 (~CS); also elsewhere on the board
GND: C35.2, C36.1, U7.3 (DCX_RS), U7.4 (GND), U7.19 (IM0), U7.21 (GND), U7.23 (MIPI_CLKP), U7.25 (MIPI_CLKN), U7.27 (GND), U7.28 (GND), U7.29 (MIPI_D0P), U7.31 (MIPI_D0N), U7.33 (GND); also elsewhere on the board
VSYS: C35.1, U7.18 (VBAT), U7.20 (VBAT); also elsewhere on the board

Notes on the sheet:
IM0/IM1 low/high = QSPI mode
DO0180FMST03 = non-lens version DO0180FMST05 = lens version
Decoupling and bulk

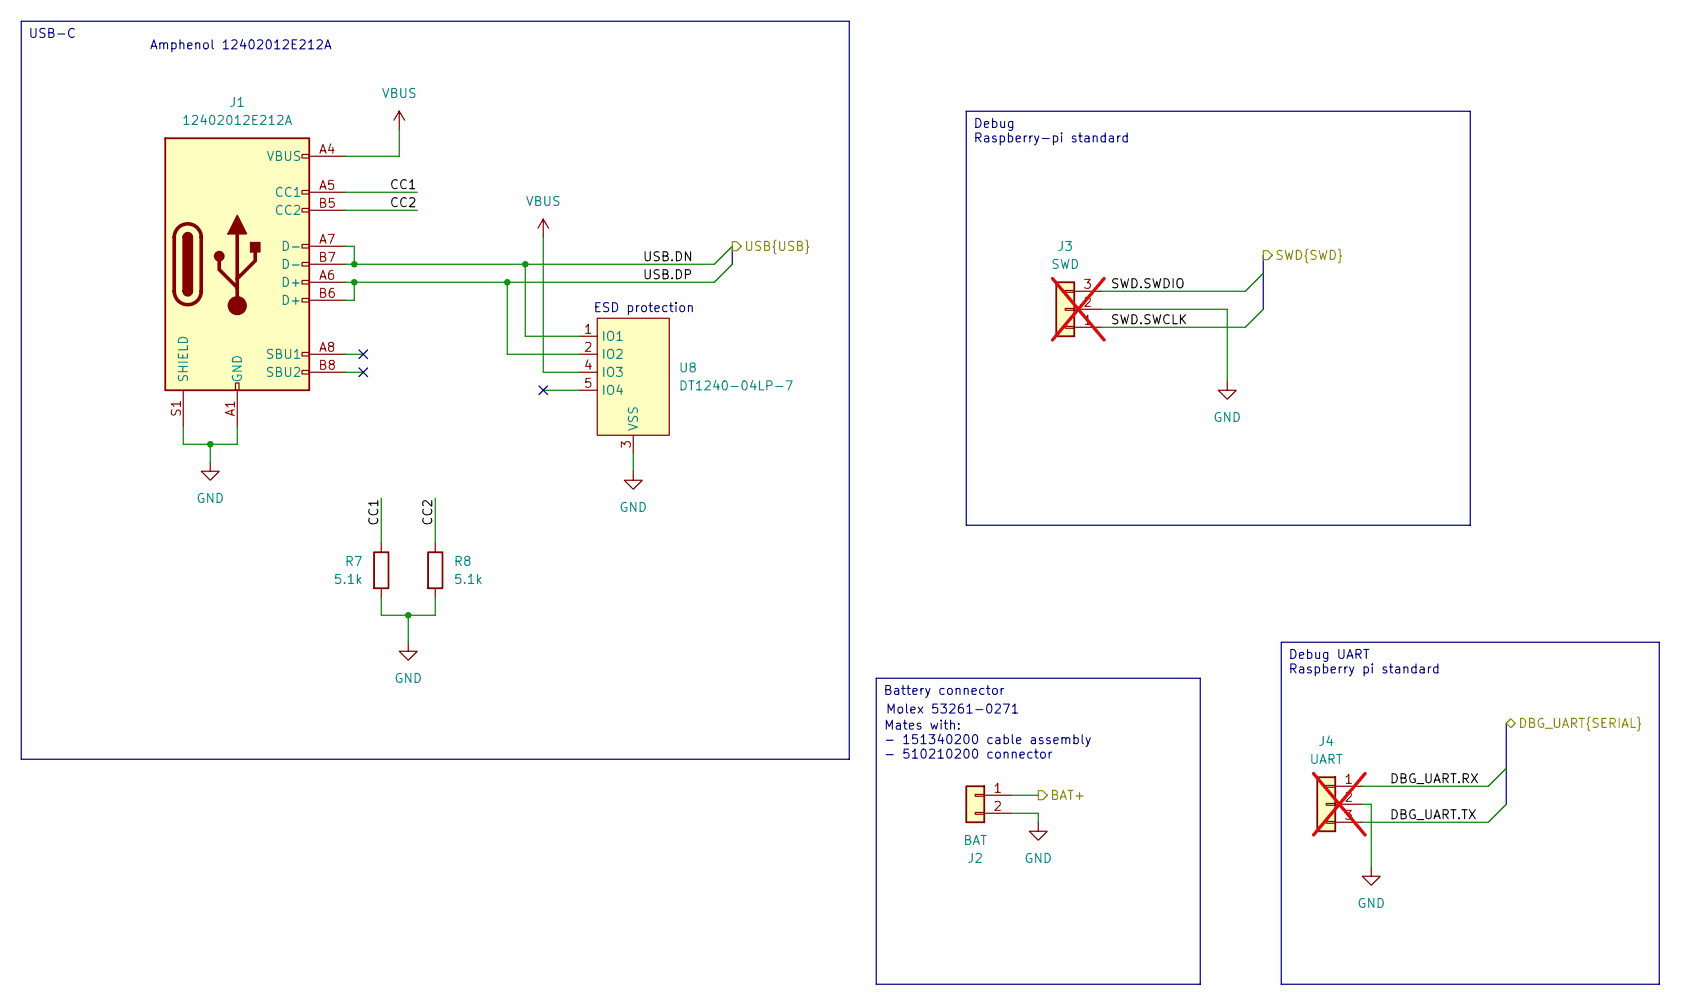
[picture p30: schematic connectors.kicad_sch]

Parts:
J1: 12402012E212A; USB_C_Receptacle_GCT_USB4105-xx-A_16P_TopMnt_Horizontal
J2: BAT; Molex_PicoBlade_53261-0271_1x02-1MP_P1.25mm_Horizontal
J3: SWD; JST_SH_SM03B-SRSS-TB_1x03-1MP_P1.00mm_Horizontal_wider; not fitted
J4: UART; JST_SH_SM03B-SRSS-TB_1x03-1MP_P1.00mm_Horizontal_wider; not fitted
R7, R8: 5.1k; R_0402_1005Metric
U8: DT1240-04LP-7; U-DFN2510-10_oneside

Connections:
/connectors/BAT+: J2.1; also elsewhere on the board
/connectors/CC1: J1.A5 (CC1), R7.1
/connectors/CC2: J1.B5 (CC2), R8.1
/connectors/DBG_UART.RX: J4.1; also elsewhere on the board
/connectors/DBG_UART.TX: J4.3; also elsewhere on the board
/connectors/SWD.SWCLK: J3.1; also elsewhere on the board
/connectors/SWD.SWDIO: J3.3; also elsewhere on the board
/connectors/USB.DN: J1.A7 (D-), J1.B7 (D-), U8.1 (IO1); also elsewhere on the board
/connectors/USB.DP: J1.A6 (D+), J1.B6 (D+), U8.2 (IO2); also elsewhere on the board
GND: J1.A1 (GND), J1.A12 (GND), J1.B1 (GND), J1.B12 (GND), J1.S1 (SHIELD), J2.2, J3.2, J4.2, R7.2, R8.2, U8.3 (VSS), U8.8 (VSS); also elsewhere on the board
VBUS: J1.A4 (VBUS), J1.A9 (VBUS), J1.B4 (VBUS), J1.B9 (VBUS), U8.4 (IO3); also elsewhere on the board

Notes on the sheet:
ESD protection
Mates with: - 151340200 cable assembly - 510210200 connector
Molex 53261-0271
Amphenol 12402012E212A
Battery connector
USB-C
Debug UART Raspberry pi standard
Debug Raspberry-pi standard

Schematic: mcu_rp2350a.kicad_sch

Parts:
C1, C37: 4.7u; C_0402_1005Metric_Smaller
C2, C4: 15p; C_0402_1005Metric
C3, C7: 4.7u; C_0402_1005Metric
C5, C6, C8, C9, C10, C11, C12, C13, C14: 0.1u; C_0402_1005Metric
L1: 3.3u; L_0805_2016Metric
R1: 47R; R_0402_1005Metric
R2, R3, R4: 1k; R_0402_1005Metric
R5, R6: 22R; R_0402_1005Metric
R23, R24: 5.1k; R_0402_1005Metric
SW1: ~{BOOT}; 435151014824
SW2: RUN; 435151014824
TP5: SDA; TestPoint_Pad_D1.0mm_Nosilk
TP12: 1V1; TestPoint_Pad_D1.0mm_Nosilk
TP13: SCL; TestPoint_Pad_D1.0mm_Nosilk
U1: RP2350A-QFN60; QFN-60-1EP_7x7mm_P0.4mm_EP3.4x3.4mm_ThermalVias
Y1: ABM8-272-T3; ABM8272T3

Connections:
+1.1V: C1.1, C5.1, C6.1, C7.1, L1.1, TP12.1 (1_1), U1.6 (DVDD), U1.23 (DVDD), U1.39 (DVDD), U1.50 (VREG_FB)
+3.3V: C8.1, C9.1, C10.1, C11.1, C12.1, C13.1, C14.1, C37.1, R1.1, R23.1, R24.1, U1.1 (IOVDD), U1.11 (IOVDD), U1.20 (IOVDD), U1.30 (IOVDD), U1.38 (IOVDD), U1.44 (ADC_AVDD), U1.45 (IOVDD), U1.49 (VREG_VIN), U1.53 (USB_OTP_VDD), U1.54 (QSPI_IOVDD); also elsewhere on the board
/ACCEL_INT: U1.35 (GPIO23); also elsewhere on the board
/IRDA_SD: U1.17 (GPIO13); also elsewhere on the board
/SOUND: U1.4 (GPIO2); also elsewhere on the board
/TP_INT: U1.27 (GPIO16); also elsewhere on the board
/TP_RESET: U1.28 (GPIO17); also elsewhere on the board
/accel/SPI.MISO: U1.32 (GPIO20); also elsewhere on the board
/accel/SPI.MOSI: U1.31 (GPIO19); also elsewhere on the board
/accel/SPI.SCK: U1.29 (GPIO18); also elsewhere on the board
/buttons/BUT.L: U1.37 (GPIO25); also elsewhere on the board
/buttons/BUT.M: U1.40 (GPIO26_ADC0); also elsewhere on the board
/buttons/BUT.R: U1.41 (GPIO27_ADC1); also elsewhere on the board
/connectors/DBG_UART.RX: U1.43 (GPIO29_ADC3); also elsewhere on the board
/connectors/DBG_UART.TX: U1.42 (GPIO28_ADC2); also elsewhere on the board
/connectors/SWD.SWCLK: U1.24 (SWCLK); also elsewhere on the board
/connectors/SWD.SWDIO: U1.25 (SWDIO); also elsewhere on the board
/connectors/USB.DN: R6.2; also elsewhere on the board
/connectors/USB.DP: R5.2; also elsewhere on the board
/flash/QSPI.SCK: U1.56 (QSPI_SCLK); also elsewhere on the board
/flash/QSPI.SD0: U1.57 (QSPI_SD0); also elsewhere on the board
/flash/QSPI.SD1: U1.59 (QSPI_SD1); also elsewhere on the board
/flash/QSPI.SD2: U1.58 (QSPI_SD2); also elsewhere on the board
/flash/QSPI.SD3: U1.55 (QSPI_SD3); also elsewhere on the board
/flash/~CS: R3.2, U1.60 (QSPI_SS); also elsewhere on the board
/irda/IRDA.RX: U1.18 (GPIO14); also elsewhere on the board
/irda/IRDA.TX: U1.19 (GPIO15); also elsewhere on the board
/mcu/I2C.SCL: R24.2, TP13.1 (1_1), U1.3 (GPIO1); also elsewhere on the board
/mcu/I2C.SDA: R23.2, TP5.1 (1_1), U1.2 (GPIO0); also elsewhere on the board
/mcu/RTC_CLK: U1.34 (GPIO22); also elsewhere on the board
/mcu/RUN: R2.2, U1.26 (RUN)
/mcu/SCREEN_AUX.PWR_EN: U1.8 (GPIO5); also elsewhere on the board
/mcu/SCREEN_AUX.~RST: U1.16 (GPIO12); also elsewhere on the board
/mcu/SCREEN_DATA.SCK: U1.10 (GPIO7); also elsewhere on the board
/mcu/SCREEN_DATA.SD0: U1.15 (GPIO11); also elsewhere on the board
/mcu/SCREEN_DATA.SD1: U1.14 (GPIO10); also elsewhere on the board
/mcu/SCREEN_DATA.SD2: U1.13 (GPIO9); also elsewhere on the board
/mcu/SCREEN_DATA.SD3: U1.12 (GPIO8); also elsewhere on the board
/mcu/SW_RUN_P: R2.1, SW2.2 (B)
/mcu/VREG_AVDD: C3.1, R1.2, U1.46 (VREG_AVDD)
/mcu/VREG_LX: L1.2, U1.48 (VREG_LX)
/mcu/XIN: C2.1, U1.21 (XIN), Y1.1
/mcu/XOUT: R4.2, U1.22 (XOUT)
/mcu/~BOOT: R3.1, SW1.2 (B)
/~ACCEL_CS: U1.33 (GPIO21); also elsewhere on the board
/~BAT_CE: U1.7 (GPIO4); also elsewhere on the board
/~BAT_INT: U1.5 (GPIO3); also elsewhere on the board
/~EEPROM_CS: U1.36 (GPIO24); also elsewhere on the board
/~SCREEN_CS: U1.9 (GPIO6); also elsewhere on the board
GND: C1.2, C2.2, C3.2, C4.2, C5.2, C6.2, C7.2, C8.2, C9.2, C10.2, C11.2, C12.2, C13.2, C14.2, C37.2, SW1.1 (A), SW1.3 (SHIELD), SW2.1 (A), SW2.3 (SHIELD), U1.47 (VREG_PGND), U1.61 (GND), Y1.2, Y1.4; also elsewhere on the board
unnamed: C4.1, R4.1, Y1.3
unnamed: R6.1, U1.51 (USB_DM)
unnamed: R5.1, U1.52 (USB_DP)

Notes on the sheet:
I2C0
"33R and 4.7u is adequate" -3 dB cutoff (1/2piRC) for 33R is 1026 Hz. 47R is 720 Hz.
4.7u specifically on pin 23
Ensure ground plane is >1.0 mm from surface
SPI0
PIO
Boot and reset buttons
Bus pullups
Decoupling and bulk
Test Points
12MHz Crystal
MCU 1.1V regulator

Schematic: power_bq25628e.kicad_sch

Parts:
C25, C26, C34: 4.7u; C_0402_1005Metric
C27, C28, C33: 10u; C_0603_1608Metric
C29, C30: 47u; C_0805_2012Metric
C31: 47n; C_0402_1005Metric
C32: 0.1u; C_0402_1005Metric
D1: ~{STAT}; LED_0402_1005Metric
L2: 1.1u; L_0603_1608Metric
L3: 2.2u; L_0805_2012Metric
R19, R21: 5.1k; R_0402_1005Metric
R20: 30k; R_0603_1608Metric
R22: 1k; R_0402_1005Metric
TH1: 10k; R_0402_1005Metric
TP1: ~{PG}; TestPoint_Pad_D1.0mm_Nosilk
TP2: ~{QON}; TestPoint_Pad_D1.0mm_Nosilk
U6: BQ25628ERYKR
U9: RT6150B-33GQW; SON50P250X250X80-11N-D

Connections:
+3.3V: C30.1, R22.1, U9.1 (VOUT), U9.10 (FB); also elsewhere on the board
/connectors/BAT+: C25.1, U6.8 (BAT+); also elsewhere on the board
/mcu/I2C.SCL: U6.13 (SCL); also elsewhere on the board
/mcu/I2C.SDA: U6.12 (SDA); also elsewhere on the board
/power/PMID: C32.1, C33.1, U6.17 (PMID)
/power/SW: C31.1, L2.1, U6.16 (SW)
/power/TS: R19.2, R20.1, TH1.1, U6.6 (TS)
/power/TS_BIAS: R19.1, U6.5 (TS_BIAS)
/power/~PG: TP1.1 (1_1), U6.3 (~PG)
/power/~QON: TP2.1 (1_1), U6.7 (~QON)
/power/~STAT: D1.1 (K), U6.10 (STAT)
/~BAT_CE: U6.14 (~CE); also elsewhere on the board
/~BAT_INT: U6.11 (~INT); also elsewhere on the board
GND: C25.2, C26.2, C27.2, C28.2, C29.2, C30.2, C32.2, C33.2, C34.2, R20.2, R21.2, TH1.2, U6.15 (GND), U9.3 (GND), U9.7 (PS), U9.9 (GND), U9.11 (GND_PAD); also elsewhere on the board
unnamed: D1.2 (A), R22.2
unnamed: C31.2, U6.1 (BTST)
unnamed: R21.1, U6.4 (ILIM)
unnamed: C34.1, U6.2 (REGN)
unnamed: L3.1, U9.4 (LX1)
unnamed: L3.2, U9.2 (LX2)
VBUS: C26.1, U6.18 (VBUS); also elsewhere on the board
VSYS: C27.1, C28.1, C29.1, L2.2, U6.9 (SYS), U9.5 (VIN), U9.6 (EN), U9.8 (VINA); also elsewhere on the board

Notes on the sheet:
Datasheet recommends: CVBUS > 1u CPMID > 10u CSYS > 20u CBAT > 10u
I_ILIM = K_ILIM/R_ILIM K_ILIM = 2500 +/-250 5.1k = 490 mA
I think stuck at 47n. Its a bootstrap so keep to recommended.
Datasheet: 5.32k
Datasheet: 30.1k
PS low = power save mode (unknown switching method) PS high = PWM mode @ 1 MHz
Thermistor
PMIC battery charger with power path
Indicator LEDs
Unused pins
Decoupling, smoothing and bulk
3.3V switching regulator Basically taken from pico 2 datasheet/schematic

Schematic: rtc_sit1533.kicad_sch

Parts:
TP3: 32k; TestPoint_Pad_D1.0mm_Nosilk
TP4: GND; TestPoint_Pad_D1.0mm_Nosilk
Y2: SIT1533AI-H4-DCC-32.768E; SIT1533AIH4DCC32768E; Mouser Part Number 788-1533AIH4DCC32.76

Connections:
+3.3V: Y2.4 (VDD); also elsewhere on the board
/mcu/RTC_CLK: TP3.1 (1_1), Y2.3 (CLK_OUT); also elsewhere on the board
GND: TP4.1 (1_1), Y2.2 (GND); also elsewhere on the board

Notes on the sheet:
32768 Hz 75 ppm stability from -10 C to +70 C 20 ppm tolerance 1 ppm aging (1 year) = ~100 ppm = +/-4 Hz = ~ 9 seconds/day max drift

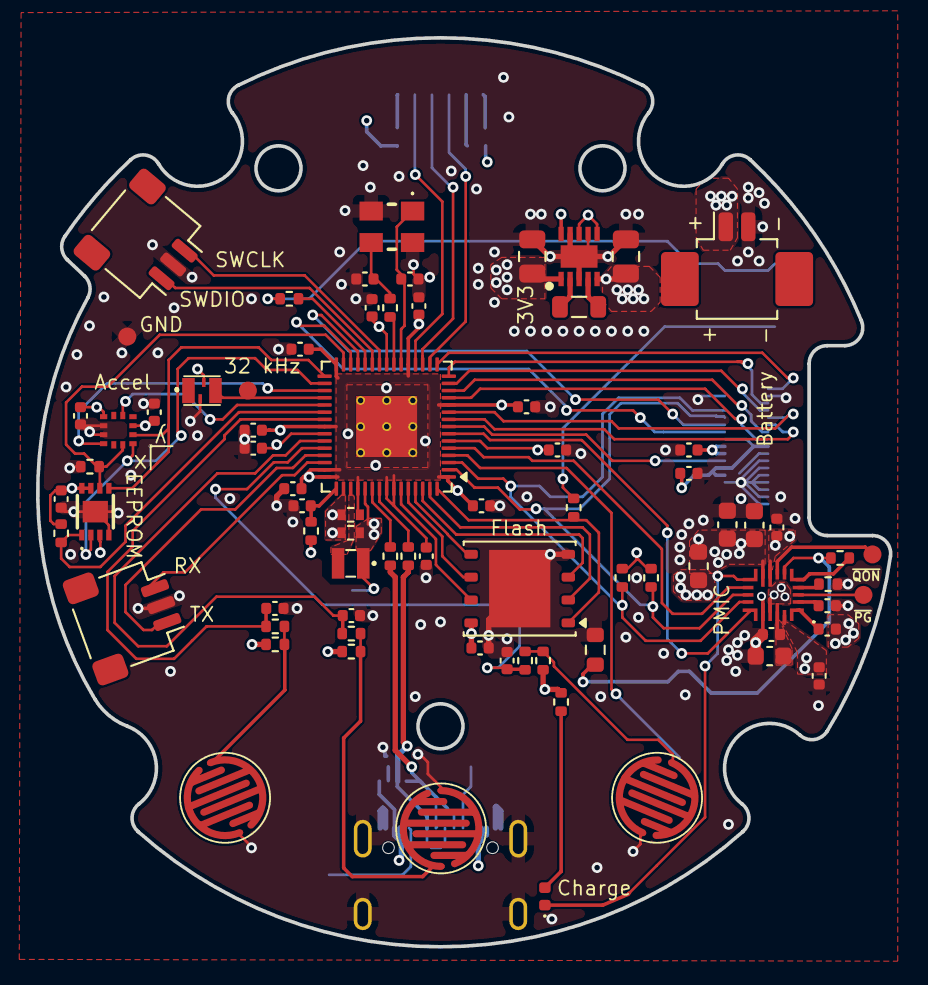
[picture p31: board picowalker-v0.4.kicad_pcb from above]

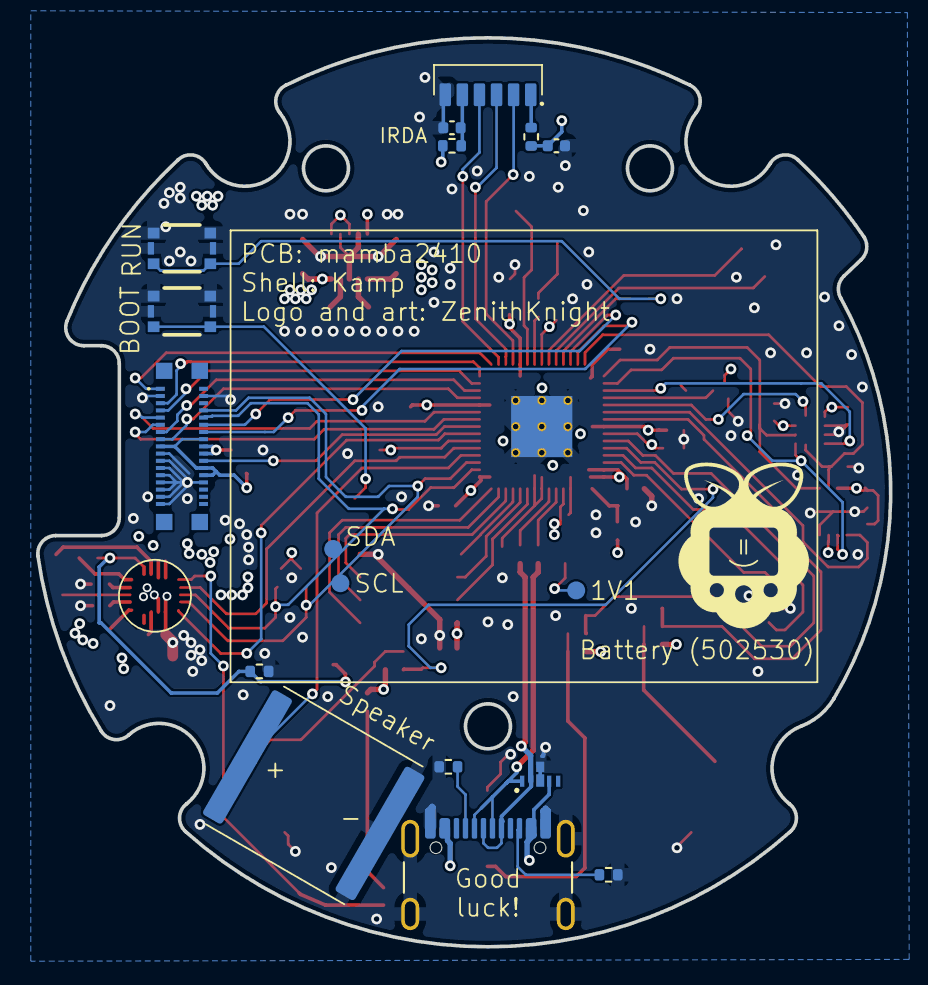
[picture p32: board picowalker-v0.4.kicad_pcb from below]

Board: 4 copper layers, 47.4 x 50.5 mm, 93 parts (17 on the bottom side), 76 nets.

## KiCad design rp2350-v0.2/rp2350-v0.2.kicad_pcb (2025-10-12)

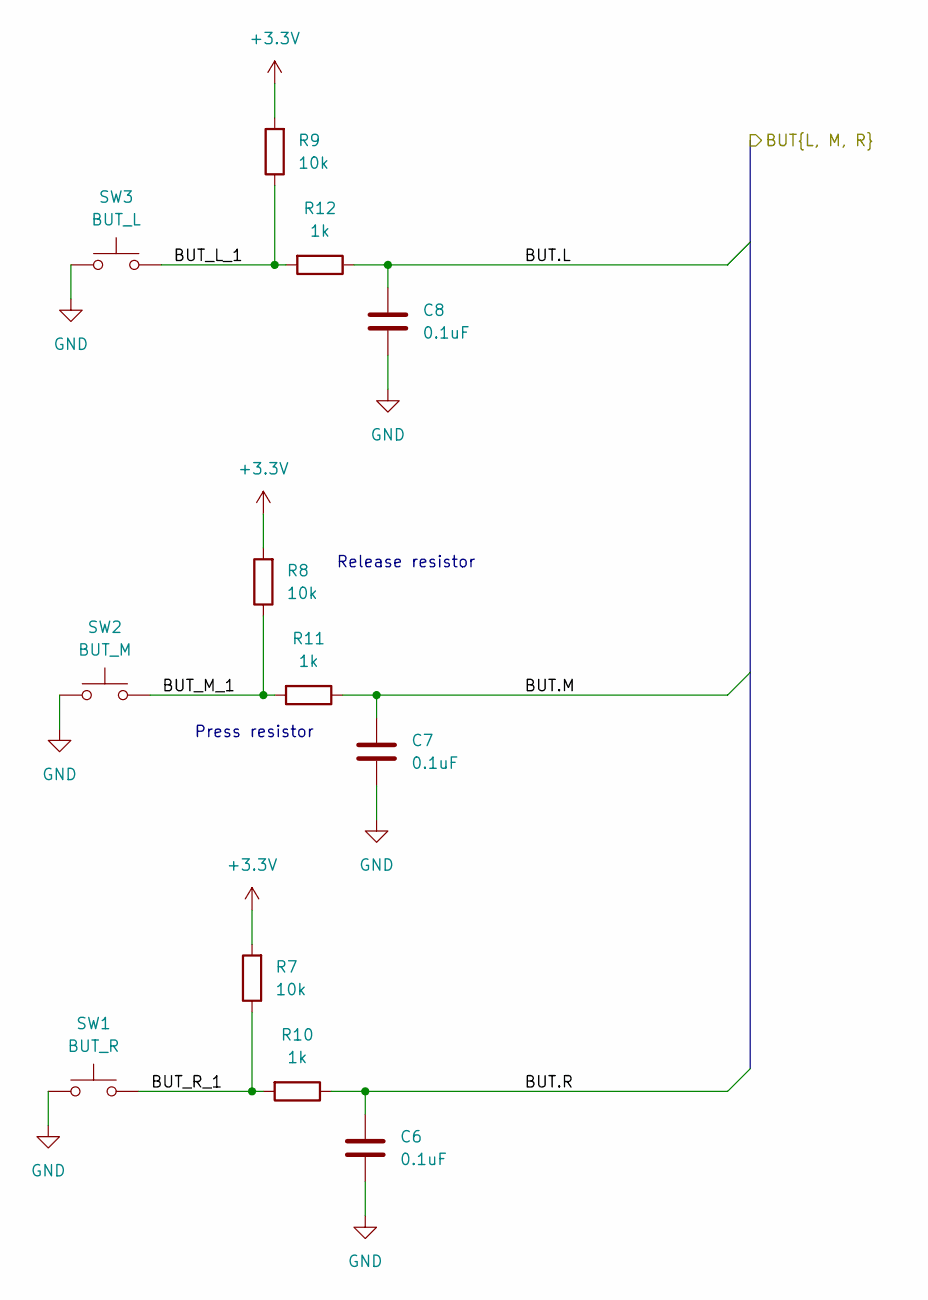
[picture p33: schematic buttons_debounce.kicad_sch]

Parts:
C6, C7, C8: 0.1uF; C_0402_1005Metric
R7, R8, R9: 10k; R_0402_1005Metric
R10, R11, R12: 1k; R_0402_1005Metric
SW1: BUT_R; SW_SPST_Omron_B3FS-101xP
SW2: BUT_M; SW_SPST_Omron_B3FS-101xP
SW3: BUT_L; SW_SPST_Omron_B3FS-101xP

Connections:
+3.3V: R7.2, R8.2, R9.2; also elsewhere on the board
/buttons/BUT.L: C8.1, R12.1; also elsewhere on the board
/buttons/BUT.M: C7.1, R11.1; also elsewhere on the board
/buttons/BUT.R: C6.1, R10.1; also elsewhere on the board
/buttons/BUT_L_1: R9.1, R12.2, SW3.2
/buttons/BUT_M_1: R8.1, R11.2, SW2.2
/buttons/BUT_R_1: R7.1, R10.2, SW1.2
GND: C6.2, C7.2, C8.2, SW1.1, SW2.1, SW3.1; also elsewhere on the board

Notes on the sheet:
Press resistor
Release resistor

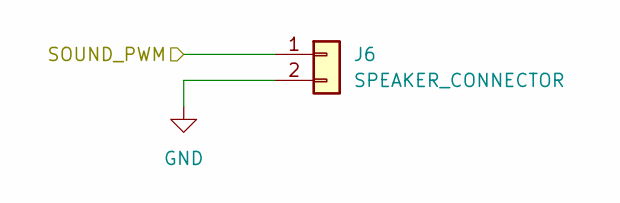
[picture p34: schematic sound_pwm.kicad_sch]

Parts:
J6: SPEAKER_CONNECTOR; PinHeader_1x02_P2.54mm_Vertical

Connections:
/mcu/SOUND_PWM: J6.1; also elsewhere on the board
GND: J6.2; also elsewhere on the board

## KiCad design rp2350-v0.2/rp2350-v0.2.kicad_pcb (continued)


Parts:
C22, C23, C27, C28, C29, C30, C31, C32, C33: 0.1uF; C_0402_1005Metric
C24, C34, C35, C36: 4.7uF; C_0402_1005Metric
C37, C38: 15pF; C_0201_0603Metric
D1: USER_LED; LED_0402_1005Metric
JP6: MCU_PWR; BridgedJumper_P2.54mm
L3: 3.3uF; L_0805_2016Metric
R24, R25: 10k; R_0402_1005Metric
R29, R30, R34, R35: 1k; R_0402_1005Metric
R31, R32: 22R; R_0402_1005Metric
R33: 33R; R_0402_1005Metric; Tolerance 1%
SW4: RUN; WS_TASV_435151014824
SW5: BOOTSEL; WS_TASV_435151014824
TP2: MCU_1V1; TestPoint_Pad_2.5x2.5mm
TP3: GP19; TestPoint_Pad_2.5x2.5mm
TP9: GP18; TestPoint_Pad_2.5x2.5mm
U1: RP2350A-QFN60; RP2350A_QFN-60_EP_7.75x7.75_Pitch0.4mm
Y1: ABM8-272-T3; ABM8272T3
Y2: SIT1533AI-H4-DCC-32.768E; SIT1533AIH4DCC32768E; Mouser Part Number 788-1533AIH4DCC32.76

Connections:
+3.3V: JP6.1 (A), R24.1, R25.1; also elsewhere on the board
/accel/ACCEL_INT: U1.34 (GPIO22); also elsewhere on the board
/accel/SPI.MISO: U1.42 (GPIO28_ADC2); also elsewhere on the board
/accel/SPI.MOSI: U1.41 (GPIO27_ADC1); also elsewhere on the board
/accel/SPI.SCK: U1.40 (GPIO26_ADC0); also elsewhere on the board
/accel/~ACCEL_CSB: U1.33 (GPIO21); also elsewhere on the board
/buttons/BUT.L: U1.35 (GPIO23); also elsewhere on the board
/buttons/BUT.M: U1.37 (GPIO25); also elsewhere on the board
/buttons/BUT.R: U1.7 (GPIO4); also elsewhere on the board
/connectors/DBG_UART.RX: U1.28 (GPIO17); also elsewhere on the board
/connectors/DBG_UART.TX: U1.27 (GPIO16); also elsewhere on the board
/connectors/SWD.SWCLK: U1.24 (SWCLK); also elsewhere on the board
/connectors/SWD.SWDIO: U1.25 (SWDIO); also elsewhere on the board
/connectors/USB.D+: R31.2; also elsewhere on the board
/connectors/USB.D-: R32.2; also elsewhere on the board
/eeprom/~EEPROM_CSB: U1.43 (GPIO29_ADC3); also elsewhere on the board
/flash/QSPI0.SCLK: U1.56 (QSPI_SCLK); also elsewhere on the board
/flash/QSPI0.SD0: U1.57 (QSPI_SD0); also elsewhere on the board
/flash/QSPI0.SD1: U1.59 (QSPI_SD1); also elsewhere on the board
/flash/QSPI0.SD2: U1.58 (QSPI_SD2); also elsewhere on the board
/flash/QSPI0.SD3: U1.55 (QSPI_SD3); also elsewhere on the board
/flash/QSPI0.SS: R35.1, U1.60 (QSPI_SS); also elsewhere on the board
/irda/IRDA.RX: U1.18 (GPIO14); also elsewhere on the board
/irda/IRDA.SD: U1.19 (GPIO15); also elsewhere on the board
/irda/IRDA.TX: U1.17 (GPIO13); also elsewhere on the board
/mcu/GPIO18: R34.1, TP9.1, U1.29 (GPIO18)
/mcu/GPIO19: TP3.1, U1.31 (GPIO19)
/mcu/I2C.SCL: R25.2, U1.3 (GPIO1); also elsewhere on the board
/mcu/I2C.SDA: R24.2, U1.2 (GPIO0); also elsewhere on the board
/mcu/MCU_1V1: C22.1, C23.1, C24.1, C34.1, L3.1, TP2.1, U1.6 (DVDD), U1.23 (DVDD), U1.39 (DVDD), U1.50 (VREG_FB)
/mcu/MCU_3V3: C27.1, C28.1, C29.1, C30.1, C31.1, C32.1, C33.1, C35.1, JP6.2 (B), R33.1, U1.1 (IOVDD), U1.11 (IOVDD), U1.20 (IOVDD), U1.30 (IOVDD), U1.38 (IOVDD), U1.44 (ADC_AVDD), U1.45 (IOVDD), U1.49 (VREG_VIN), U1.53 (USB_OTP_VDD), U1.54 (QSPI_IOVDD), Y2.4 (VDD)
/mcu/PWR_AUX.~BAT_CE: U1.4 (GPIO2); also elsewhere on the board
/mcu/PWR_AUX.~BAT_INT: U1.5 (GPIO3); also elsewhere on the board
/mcu/QSPI1.SCK: U1.12 (GPIO8); also elsewhere on the board
/mcu/QSPI1.SDIO0: U1.16 (GPIO12); also elsewhere on the board
/mcu/QSPI1.SDIO1: U1.15 (GPIO11); also elsewhere on the board
/mcu/QSPI1.SDIO2: U1.14 (GPIO10); also elsewhere on the board
/mcu/QSPI1.SDIO3: U1.13 (GPIO9); also elsewhere on the board
/mcu/RTC_XO: U1.32 (GPIO20), Y2.3 (CLK_OUT)
/mcu/SCREEN_AUX.PWR_EN: U1.8 (GPIO5); also elsewhere on the board
/mcu/SCREEN_AUX.~CSB: U1.10 (GPIO7); also elsewhere on the board
/mcu/SCREEN_AUX.~RST: U1.9 (GPIO6); also elsewhere on the board
/mcu/SOUND_PWM: U1.36 (GPIO24); also elsewhere on the board
/mcu/VREG_AVDD: C36.1, R33.2, U1.46 (VREG_AVDD)
/mcu/VREG_LX: L3.2, U1.48 (VREG_LX)
/mcu/XIN: C37.1, U1.21 (XIN), Y1.1
/mcu/XOUT: R29.2, U1.22 (XOUT)
/mcu/~USB_BOOT: R35.2, SW5.3, SW5.4
GND: C22.2, C23.2, C24.2, C27.2, C28.2, C29.2, C30.2, C31.2, C32.2, C33.2, C34.2, C35.2, C36.2, C37.2, C38.2, D1.1 (K), R30.1, SW4.5 (SHLD), SW4.6 (SHLD), SW5.1, SW5.2, SW5.5 (SHLD), SW5.6 (SHLD), U1.47 (VREG_PGND), U1.61 (GND), Y1.2, Y1.4, Y2.2 (GND); also elsewhere on the board
unnamed: C38.1, R29.1, Y1.3
unnamed: D1.2 (A), R34.2
unnamed: R30.2, SW4.1, SW4.2
unnamed: SW4.3, SW4.4, U1.26 (RUN)
unnamed: R32.1, U1.51 (USB_DM)
unnamed: R31.1, U1.52 (USB_DP)

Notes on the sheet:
PIO
TODO: Check if caps are the right value on a 4 layer board
PIO. Note decreasing numbers, so need to swap nibbles in software.
27R ideal, 22R is common value
SPI1
VREG SMPS
Decoupling and bulk
RTC clock
I2C pullups
12MHz Crystal


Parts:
C1: 0.1uF; C_0402_1005Metric
IC1: M95512-RMN6TP; SOIC127P600X175-8N; Mouser Part Number 511-M95512-RMN6TP
JP1: EEPROM_PWR; BridgedJumper_P2.54mm
R3, R4: 10k; R_0402_1005Metric

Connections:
+3.3V: JP1.1 (A); also elsewhere on the board
/accel/SPI.MISO: IC1.2 (Q); also elsewhere on the board
/accel/SPI.MOSI: IC1.5 (D); also elsewhere on the board
/accel/SPI.SCK: IC1.6 (C), R4.1; also elsewhere on the board
/eeprom/EEPROM_3V3: C1.1, IC1.3 (~W), IC1.7 (~HOLD), IC1.8 (VCC), JP1.2 (B), R3.1
/eeprom/~EEPROM_CSB: IC1.1 (~S), R3.2; also elsewhere on the board
GND: C1.2, IC1.4 (VSS), R4.2; also elsewhere on the board

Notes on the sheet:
Needs hardware pull-up to follow correct power-on sequence.
Must be run in SPI 00 mode. Pull-down may not be needed, but is apparently strongly recommended.


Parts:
J1: USB4215-03-A; GCT_USB4215_03_A
J2: SWD; JST_SH_SM03B-SRSS-TB_1x03-1MP_P1.00mm_Horizontal
J3: BAT; JST_PH_S2B-PH-K_1x02_P2.00mm_Horizontal
J5: UART; JST_SH_SM03B-SRSS-TB_1x03-1MP_P1.00mm_Horizontal
R1, R2: 5.1k; R_0402_1005Metric

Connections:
/connectors/BAT+: J3.1; also elsewhere on the board
/connectors/CC1: J1.A5 (CC1), R1.1
/connectors/CC2: J1.B5 (CC2), R2.1
/connectors/DBG_UART.RX: J5.1; also elsewhere on the board
/connectors/DBG_UART.TX: J5.3; also elsewhere on the board
/connectors/SWD.SWCLK: J2.1; also elsewhere on the board
/connectors/SWD.SWDIO: J2.3; also elsewhere on the board
/connectors/USB.D+: J1.A6 (D+), J1.B6 (D+); also elsewhere on the board
/connectors/USB.D-: J1.A7 (D-), J1.B7 (D-); also elsewhere on the board
GND: J1.A1 (GND), J1.A12 (GND), J1.B1 (GND), J1.B12 (GND), J1.S1 (SHIELD), J2.2, J3.2, J5.2, R1.2, R2.2; also elsewhere on the board
VBUS: J1.A4 (VBUS), J1.A9 (VBUS), J1.B4 (VBUS), J1.B9 (VBUS); also elsewhere on the board

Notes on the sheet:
Debug UART Raspberry pi standard (double check)
USB-C
Debug Raspberry-pi standard
CC lines
Battery JST


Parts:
C19, C20, C21: 10uF; C_0603_1608Metric
J4: DO0180FMST08; AXE534127; Mouser Part Number 679-AXE534127
JP4: IO_PWR; BridgedJumper_P2.54mm
JP5: PANEL_PWR; BridgedJumper_P2.54mm
R20, R21, R22: 0R; R_0603_1608Metric
R23: 100k; R_0603_1608Metric; not fitted
TP4: TP_SDA; TestPoint_Pad_1.0x1.0mm
TP5: TP_SCL; TestPoint_Pad_1.0x1.0mm
TP6: TP_INT; TestPoint_Pad_1.0x1.0mm
TP7: TP_RESET; TestPoint_Pad_1.0x1.0mm
TP8: TP_VCC; TestPoint_Pad_1.0x1.0mm
TP10: TE; TestPoint_Pad_1.0x1.0mm

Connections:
+3.3V: JP4.1 (A); also elsewhere on the board
/mcu/QSPI1.SCK: J4.9 (SCL); also elsewhere on the board
/mcu/QSPI1.SDIO0: J4.5 (SDI_SDIO0); also elsewhere on the board
/mcu/QSPI1.SDIO1: J4.7 (SDO_SDI1); also elsewhere on the board
/mcu/QSPI1.SDIO2: J4.13 (SDI2); also elsewhere on the board
/mcu/QSPI1.SDIO3: J4.15 (SDI3); also elsewhere on the board
/mcu/SCREEN_AUX.PWR_EN: J4.22 (PWR_EN); also elsewhere on the board
/mcu/SCREEN_AUX.~CSB: J4.11 (CS); also elsewhere on the board
/mcu/SCREEN_AUX.~RST: J4.1 (RESET); also elsewhere on the board
/screen/SCREEN_3V3: C21.1, J4.16 (TP_VCC), J4.24 (VCI), J4.26 (VDDIO), JP4.2 (B), R21.2, TP8.1
/screen/SCREEN_VSYS: C19.2, C20.1, J4.18 (VBAT), J4.20 (VBAT), JP5.2 (B)
/screen/TP_AUX.INT: J4.12 (TP_INT), TP6.1
/screen/TP_AUX.RESET: J4.14 (TP_RESET), TP7.1
/screen/TP_I2C.SCL: J4.8 (TP_SCL), TP5.1
/screen/TP_I2C.SDA: J4.10 (TP_SDA), TP4.1
GND: C19.1, C20.2, C21.2, J4.4 (GND), J4.21 (GND), J4.23 (MIPI_CLKP), J4.25 (MIPI_CLKN), J4.27 (GND), J4.28 (GND), J4.29 (MIPI_D0P), J4.31 (MIPI_D0N), J4.33 (GND), R20.1, R22.1, R23.2; also elsewhere on the board
unnamed: J4.3 (DCX_RS), R22.2
unnamed: J4.19 (IM0), R20.2
unnamed: J4.17 (IM1), R21.1
unnamed: J4.2 (TE), R23.1, TP10.1
VSYS: JP5.1 (A); also elsewhere on the board

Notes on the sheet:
TE is output, NC is probably fine
Power sense


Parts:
C39: 0.1uF; C_0402_1005Metric
C40: 4.7uF; C_0402_1005Metric
IC5: W25Q128JVSIM_TR; SOIC127P790X216-8N; Mouser Part Number 454-W25Q128JVSIMTR
JP7: FLASH_PWR; BridgedJumper_P2.54mm

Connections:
+3.3V: JP7.2 (B); also elsewhere on the board
/flash/FLASH_3V3: C39.1, C40.1, IC5.8 (VCC), JP7.1 (A)
/flash/QSPI0.SCLK: IC5.6 (CLK); also elsewhere on the board
/flash/QSPI0.SD0: IC5.5 (DI_(IO0)); also elsewhere on the board
/flash/QSPI0.SD1: IC5.2 (DO_(IO1)); also elsewhere on the board
/flash/QSPI0.SD2: IC5.3 (/WP_(IO2)); also elsewhere on the board
/flash/QSPI0.SD3: IC5.7 (/HOLD_OR_/RESET_(IO3)); also elsewhere on the board
/flash/QSPI0.SS: IC5.1 (/CS); also elsewhere on the board
GND: C39.2, C40.2, IC5.4 (GND); also elsewhere on the board


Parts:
C2: 0.1uF; C_0402_1005Metric
C3: 4.7uF; C_0603_1608Metric
IC2: TFBS4711-TT1; TFBS4711-TR; Mouser Part Number 782-TFBS4711-TT1
JP2: IRDA_PWR; BridgedJumper_P2.54mm
R5: 47R; R_0402_1005Metric
R6: 56R; R_0402_1005Metric

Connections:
+3.3V: JP2.2 (B); also elsewhere on the board
/irda/IRDA.RX: IC2.3 (RXD); also elsewhere on the board
/irda/IRDA.SD: IC2.4 (SD); also elsewhere on the board
/irda/IRDA.TX: IC2.2 (TXD); also elsewhere on the board
/irda/IRDA_3V3: JP2.1 (A), R5.1, R6.1
GND: C2.2, C3.2, IC2.6 (GND); also elsewhere on the board
unnamed: C2.1, IC2.5 (VCC1), R5.2
unnamed: C3.1, IC2.1 (VCC2/IRED/ANODE), R6.2

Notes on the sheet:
Rec. tantalum/fast-rise. ceramic seems to work fine.
0402 1/16W seems like it works, hasn't broken yet...
Note: Cap closer than resistor in physical
Note: Resistor closer than cap in physical.

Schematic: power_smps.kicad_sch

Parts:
C9: 47nF; C_0603_1608Metric
C10, C11, C12, C14, C16: 10uF; C_0603_1608Metric
C13: 0.1uF; C_0402_1005Metric
C15: 4.7uF; C_0603_1608Metric
C17, C18: 47uF; C_0805_2012Metric; Tolerance 20%
D2: ~{STAT}; LED_0402_1005Metric
D3: ~{PG}; LED_0402_1005Metric
IC3: BQ25628ERYKR; Mouser Part Number 595-BQ25628ERYKR
IC4: RT6150B-33GQW; SON50P250X250X80-11N-D
L1: 1uH; L_0603_1608Metric
L2: 2.2uH; L_0805_2012Metric
R13: 5.3k; R_0402_1005Metric
R14: 30k; R_0603_1608Metric
R15: 5k; R_0402_1005Metric
R16, R17: 1k; R_0402_1005Metric
R18, R19: 100k; R_0603_1608Metric
TH1: 10k; R_0402_1005Metric
TP1: ~{QON}; TestPoint_Pad_2.5x2.5mm

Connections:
+3.3V: C17.1, IC4.1 (VOUT), IC4.10 (FB), R16.1, R17.1; also elsewhere on the board
/connectors/BAT+: C16.1, IC3.8 (BAT); also elsewhere on the board
/mcu/I2C.SCL: IC3.13 (SCL); also elsewhere on the board
/mcu/I2C.SDA: IC3.12 (SDA); also elsewhere on the board
/mcu/PWR_AUX.~BAT_CE: IC3.14 (~CE_1), IC3.22 (~CE_2); also elsewhere on the board
/mcu/PWR_AUX.~BAT_INT: IC3.11 (~INT); also elsewhere on the board
/power/3V3_EN: IC4.6 (EN), R19.2
/power/BTST: C9.2, IC3.1 (BTST_1), IC3.19 (BTST_2)
/power/ILIM: IC3.4 (ILIM), R15.1
/power/PMID: C13.1, C14.1, IC3.17 (PMID)
/power/PS: IC4.7 (PS), R18.1
/power/REGN: C15.1, IC3.2 (REGN)
/power/SW: C9.1, IC3.16 (SW), L1.1
/power/TS: IC3.6 (TS), R13.2, R14.1, TH1.1
/power/TS_BIAS: IC3.5 (TS_BIAS_1), IC3.20 (TS_BIAS_2), R13.1
/power/~PG: D3.1 (K), IC3.3 (~PG)
/power/~QON: IC3.7 (~QON), TP1.1
/power/~STAT: D2.1 (K), IC3.10 (STAT_1), IC3.21 (STAT_2)
GND: C10.2, C11.2, C12.2, C13.2, C14.2, C15.2, C16.2, C17.2, C18.2, IC3.15 (GND), IC4.3 (GND), IC4.9 (GND), IC4.11 (GND_PAD), R14.2, R15.2, R18.2, TH1.2; also elsewhere on the board
unnamed: D2.2 (A), R17.2
unnamed: D3.2 (A), R16.2
unnamed: IC4.4 (LX1), L2.1
unnamed: IC4.2 (LX2), L2.2
VBUS: C12.1, IC3.18 (VBUS); also elsewhere on the board
VSYS: C10.1, C11.1, C18.1, IC3.9 (SYS), IC4.5 (VIN), IC4.8 (VINA), L1.2, R19.1; also elsewhere on the board

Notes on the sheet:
Can be software disabled
I_ILIM = K_ILIM/R_ILIM K_ILIM = 2500 +/-250
Datasheet: 30.1k
Ceramic! As close to pins as possible
RT0402DRE075K3L
Decoupling and bulk, place as close to PMID/GND pins as possible
Datasheet: 5.32k
ERA-3AED303V
3.3V switching regulator Basically taken from pico 2 datasheet/schematic
Battery decouple
Thermistor
PMID pin
PMIC battery charger with power path
REGN pin
Indicator LEDs
ILIM pin
Output conditioning

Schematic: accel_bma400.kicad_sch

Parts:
AC1: BMA400; BOSCH_LGA-12; Mouser Part Number 262-BMA400
C4, C5: 0.1uF; C_0402_1005Metric
JP3: ACCEL_PWR; BridgedJumper_P2.54mm

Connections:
+3.3V: JP3.2 (B); also elsewhere on the board
/accel/ACCEL_3V3: AC1.3 (VDDIO), AC1.7 (VDD), C4.1, C5.1, JP3.1 (A)
/accel/ACCEL_INT: AC1.5 (INT1); also elsewhere on the board
/accel/SPI.MISO: AC1.1 (SDO); also elsewhere on the board
/accel/SPI.MOSI: AC1.2 (SDX); also elsewhere on the board
/accel/SPI.SCK: AC1.12 (SCX); also elsewhere on the board
/accel/~ACCEL_CSB: AC1.10 (CSB); also elsewhere on the board
GND: AC1.8 (GNDIO), AC1.9 (GND), C4.2, C5.2; also elsewhere on the board



Board: 4 copper layers, 65.0 x 65.0 mm, 114 parts (19 on the bottom side), 95 nets.

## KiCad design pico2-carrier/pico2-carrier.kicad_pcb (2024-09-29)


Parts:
AC1: BMA400; BOSCH_LGA-12; Mouser Part Number 262-BMA400
C1, C3, C4, C5, C6: 0.1uF; C_0402_1005Metric
C2: 4.7uF; C_0603_1608Metric
H1, H2, H3, H4: MountingHole; MountingHole_2.2mm_M2_DIN965_Pad_TopBottom
IC1: TFDU4101-TT3; TFDU4101-TR3-Side; Mouser Part Number 782-TFDU4101-TT3
IC2: M95512-DWDW4TP_K; SOP65P640X120-8N; Mouser Part Number 511-M95512-DWDW4TP/K
IC3: W25Q128JVSIM_TR; SOIC127P790X216-8N; Mouser Part Number 454-W25Q128JVSIMTR
JP1: VBUS_SENSE; PinHeader_1x02_P2.54mm_Vertical
JP2: VSYS_SENSE; PinHeader_1x02_P2.54mm_Vertical
JP3: 3V3_CURRENT_SENSE; PinHeader_1x02_P2.54mm_Vertical
R1: 56R; R_0402_1005Metric
R2: 47R; R_0402_1005Metric
R3: 1k; R_0402_1005Metric
R4, R5: 10k; R_0402_1005Metric
SW1: RUN; SW_SPST_Omron_B3FS-101xP
U1: Pico 2; RPi_Pico_SMD_TH

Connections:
+3.3V: AC1.3 (VDDIO), AC1.7 (VDD), C3.1, C4.1, C5.2, C6.1, IC2.3 (~W), IC2.7 (~HOLD), IC2.8 (VCC), IC3.3 (/WP_(IO2)), IC3.7 (/HOLD_OR_/RESET_(IO3)), IC3.8 (VCC), JP3.2 (B), R1.2, R2.1, R4.1, R5.1; also elsewhere on the board
/3V3_OUT: JP3.1 (A), U1.35 (ADC_VREF), U1.36 (3V3)
/ACCEL_INT1: AC1.5 (INT1), U1.11 (GPIO8)
/BUT_L: U1.31 (GPIO26_ADC0); also elsewhere on the board
/BUT_M: U1.29 (GPIO22); also elsewhere on the board
/BUT_R: U1.25 (GPIO19); also elsewhere on the board
/DBG_RX: U1.2 (GPIO1)
/DBG_TX: U1.1 (GPIO0)
/HSTX_SCK: U1.17 (GPIO13); also elsewhere on the board
/HSTX_SD0: U1.20 (GPIO15); also elsewhere on the board
/HSTX_SD1: U1.19 (GPIO14); also elsewhere on the board
/HSTX_SD2: U1.22 (GPIO17); also elsewhere on the board
/HSTX_SD3: U1.21 (GPIO16); also elsewhere on the board
/I2C_SCL: R4.2, U1.27 (GPIO21); also elsewhere on the board
/I2C_SDA: R5.2, U1.26 (GPIO20); also elsewhere on the board
/IR_PIO_RX: IC1.4 (RXD), U1.14 (GPIO10)
/IR_PIO_TX: IC1.3 (TXD), U1.15 (GPIO11)
/IR_SD: IC1.5 (SD), U1.12 (GPIO9)
/RUN: SW1.2, U1.30 (RUN)
/SPI_MISO: AC1.1 (SDO), IC2.2 (Q), IC3.2 (DO_(IO1)), U1.6 (GPIO4)
/SPI_MOSI: AC1.2 (SDX), IC2.5 (D), IC3.5 (DI_(IO0)), U1.5 (GPIO3)
/SPI_SCK: AC1.12 (SCX), IC2.6 (C), IC3.6 (CLK), U1.4 (GPIO2)
/SWCLK: U1.41 (SWCLK)
/SWDIO: U1.43 (SWDIO)
/VBUS_OUT: JP1.1 (A), U1.40 (VBUS)
/VCC1: C1.2, IC1.6 (VCC1), R2.2
/VCC2: C2.1, IC1.1 (VCC2_IRED_ANODE), R1.1
/VSYS_IN: JP2.1 (A), U1.39 (VSYS); also elsewhere on the board
/~ACCEL_CSB: AC1.10 (CSB), U1.10 (GPIO7)
/~BAT_CE: U1.34 (GPIO28_ADC2); also elsewhere on the board
/~BAT_INT: U1.32 (GPIO27_ADC1); also elsewhere on the board
/~EEPROM_CSB: IC2.1 (~S), U1.9 (GPIO6)
/~FLASH_CSB: IC3.1 (/CS), U1.7 (GPIO5)
/~SCREEN_CSB: U1.24 (GPIO18); also elsewhere on the board
/~SCREEN_RST: U1.16 (GPIO12); also elsewhere on the board
GND: AC1.8 (GNDIO), AC1.9 (GND), C1.1, C2.2, C3.2, C4.2, C5.1, C6.2, H1.1, H2.1, H3.1, H4.1, IC1.8 (GND), IC2.4 (VSS), IC3.4 (GND), R3.2, U1.3 (GND), U1.8 (GND), U1.13 (GND), U1.18 (GND), U1.23 (GND), U1.28 (GND), U1.33 (AGND), U1.38 (GND), U1.42 (GND); also elsewhere on the board
unnamed: R3.1, SW1.1
VBUS: JP1.2 (B); also elsewhere on the board
VSYS: JP2.2 (B); also elsewhere on the board

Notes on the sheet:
User buttons
Accelerometer
Sound
Image flash
Mechanical
IrDA transceiver
EEPROM
Can possibly remove
2.4V - 5.5V
Input from PMIC
200mA max
Software reset might be sufficient
Current lim = 60mA
1.7V - 5.5V at normal temperatures
Actual chip has extra 4 pins, at least 1 (the pico LED pin) can be reused in final design. 1 needs to stay as USB VBUS_SENSE (probably) GP24 - VBUS sense GP23 - SMPS power save GP25 - LED GP29 - VSYS sense
Pins on pico
Ideally DRMN (1.8V-5.5V, SO8) but I have DWDW (2.5V-5.5V, TSSOP8)
Tantalum/fast rise
Ideally TFBS4711 but I have TFDU4101 in stock
Options both compatible footprints: W25Q128JVS IS25LP128JB Package SOIC8/VSOP8
1.2V - 3.6V
Weird HSTX pins placement for better routing Can easily reconfigure in software
Ceramic
<--
Removed sound because lack of pins


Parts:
BT1: Battery_Cell; JST_PH_B2B-PH-K_1x02_P2.00mm_Vertical
C10: 47nF; C_0603_1608Metric
C11, C13, C14, C16, C17: 10uF; C_0603_1608Metric
C12: 4.7uF; C_0603_1608Metric
C15: 0.1uF; C_0402_1005Metric
D1: PG; LED_0402_1005Metric
D2: STAT; LED_0402_1005Metric
IC4: BQ25628ERYKR; Mouser Part Number 595-BQ25628ERYKR
L1: 1uH; L_0603_1608Metric
Q1: DMG2305UX-7; SOT96P240X115-3N; Mouser Part Number 621-DMG2305UX-7
R8, R9: 1k; R_0402_1005Metric
R10: 5k; R_0402_1005Metric
R16: 5.3k; R_0402_1005Metric
R17: 30k; R_0603_1608Metric
R18: 100k; R_0603_1608Metric; not fitted
TH1: 10k; R_0603_1608Metric
TP1: ~{QON}; PinHeader_1x01_P2.54mm_Vertical

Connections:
+3.3V: R8.1, R9.1; also elsewhere on the board
/I2C_SCL: IC4.13 (SCL); also elsewhere on the board
/I2C_SDA: IC4.12 (SDA); also elsewhere on the board
/battery-bq25628e/BAT+: BT1.1 (+), C13.1, IC4.8 (BAT)
/battery-bq25628e/BTST: C10.2, IC4.1 (BTST_1), IC4.19 (BTST_2)
/battery-bq25628e/ILIM: IC4.4 (ILIM), R10.1
/battery-bq25628e/PMID: C15.1, C16.1, IC4.17 (PMID)
/battery-bq25628e/REGN: C12.1, IC4.2 (REGN)
/battery-bq25628e/STAT: D2.1 (K), IC4.10 (STAT_1), IC4.21 (STAT_2)
/battery-bq25628e/SW: C10.1, IC4.16 (SW), L1.1
/battery-bq25628e/SYS: C11.1, C17.1, IC4.9 (SYS), L1.2, Q1.3 (D)
/battery-bq25628e/TS: IC4.6 (TS), R16.2, R17.1, TH1.1
/battery-bq25628e/TS_BIAS: IC4.5 (TS_BIAS_1), IC4.20 (TS_BIAS_2), R16.1
/battery-bq25628e/~PG: D1.1 (K), IC4.3 (~PG)
/battery-bq25628e/~QON: IC4.7 (~QON), TP1.1
/~BAT_CE: IC4.14 (~CE_1), IC4.22 (~CE_2); also elsewhere on the board
/~BAT_INT: IC4.11 (~INT); also elsewhere on the board
GND: BT1.2 (-), C11.2, C12.2, C13.2, C14.2, C15.2, C16.2, C17.2, IC4.15 (GND), R10.2, R17.2, R18.1, TH1.2; also elsewhere on the board
unnamed: D1.2 (A), R8.2
unnamed: D2.2 (A), R9.2
VBUS: C14.1, IC4.18 (VBUS), Q1.1 (G), R18.2; also elsewhere on the board
VSYS: Q1.2 (S); also elsewhere on the board

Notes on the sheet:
_Charge_ enable MUST be driven Software bit can override the enable
RT0402DRE075K3L
Rec. 10k resistor for pull-ups
Ceramic! As close to pins as possible
ERA-3AED303V
Datasheet: 5.32k
For pkcell 500mAh LP503035: Standard charge 0.2C, quick charge 1C Cut off current 0.01C Max discharge 1C JST-PH-2P Counterparts: - B2B-PH-K-S (Top-entry THT, cheap ~£0.15) - S2B-PH-SM4-TB (Side-entry SMD, more expensive ~£0.45)
I_ILIM = K_ILIM/R_ILIM K_ILIM = 2500 +/-250
Decoupling and bulk, place as close to PMID/GND pins as possible
Datasheet: 30.1k
Can be software disabled
~{PG} = Input power good STAT => low = charging, high = not charging, blink at 1Hz = charge suspend ~{BAT_INT} might just be good enough, it sends an interrupt whenever the status register changes. so host can read that reg and determine what happened rather than use up two more pins to get the sam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
Pico 2 has Schottky diode from VBUS to VSYS so should be ok to connect when charging Recommends having a Schottky diode so that VBUS doesn't feed back into power supply. OR have a PFET with gate controlled by VBUS for better efficiency. Recommended PFET is Diodes DMG2305UX
"The TS pin may be left floating if TS_IGNORE is set to 1" - BQ25628E datasheet 8.3.5.4
"For 103AT NTC thermistor [...] 5.32k and 30.1k for R16 and R17" - section 8.3.5.4.2
LOW=on charge, blinks 1Hz on fault Leave floating if unused
Exit ship mode/chip reset


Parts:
C18, C19, C20: 0.1uF; C_0402_1005Metric
R7: 1k; C_0402_1005Metric
R11, R12, R14: 10k; R_0402_1005Metric
R13, R15: 1k; R_0402_1005Metric
SW5: BUT_L; SW_SPST_Omron_B3FS-101xP
SW6: BUT_M; SW_SPST_Omron_B3FS-101xP
SW7: BUT_R; SW_SPST_Omron_B3FS-101xP

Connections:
+3.3V: R11.2, R12.2, R14.2; also elsewhere on the board
/BUT_L: C18.1, R7.1; also elsewhere on the board
/BUT_M: C19.1, R13.1; also elsewhere on the board
/BUT_R: C20.1, R15.1; also elsewhere on the board
/buttons-debounce/BUT_L_1: R7.2, R11.1, SW5.2
/buttons-debounce/BUT_M_1: R12.1, R13.2, SW6.2
/buttons-debounce/BUT_R_1: R14.1, R15.2, SW7.2
GND: C18.2, C19.2, C20.2, SW5.1, SW6.1, SW7.1; also elsewhere on the board

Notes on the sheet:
Release resistor
RC network + Schmitt trigger/inverter for debounce and signal cleanup There are dedicated debounce ICs but are expensive. 0.1uF + 10k = 1ms rise 0.1uF + 1k = 0.1ms fall
Press resistor
RP2350 has optional Schmitt trigger inputs (min 0.2V hysteresis) RP2350 can also pull-up buttons so maybe remove external pullup (32-86k resistors) Still need cap, 0.1uF seems fine, maybe go a bit higher to 1uF if buttons are bad.
Candidate: Omron B3FS-1010P
If want to remove debounce network, DNP inverter, cap and release resistor then bypass the jumper
10k pullup/0.1uF cap with internal schmitt trigger (on by default) seems stable


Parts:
C7, C8, C9: 10uF; C_0603_1608Metric
J2: DO0180FMST08; AXE534127; Mouser Part Number 679-AXE534127
J3: Ext_Pwr_Rail; PinHeader_2x07_P2.54mm_Vertical
JP4: JP_IM0; SolderJumper-3_P1.3mm_Bridged12_Pad1.0x1.5mm
JP5: JP_IM1; SolderJumper-3_P1.3mm_Bridged12_Pad1.0x1.5mm
JP6: SCREEN_PWR; PinHeader_1x03_P2.54mm_Vertical
JP7: PWR_EN; PinHeader_1x03_P2.54mm_Vertical
R6: 0R; C_0402_1005Metric
TP2: DCX_RS; PinHeader_1x01_P2.54mm_Vertical

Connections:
+3.3V: C7.1, J2.24 (VCI), J2.26 (VDDIO), J3.2, J3.4, J3.6, J3.8, J3.10, J3.12, J3.14, JP4.3 (B), JP5.1 (A), JP6.1 (A), JP7.3 (B); also elsewhere on the board
/HSTX_SCK: J2.9 (SCL); also elsewhere on the board
/HSTX_SD0: J2.5 (SDI_SDIO0); also elsewhere on the board
/HSTX_SD1: J2.7 (SDO_SDI1); also elsewhere on the board
/HSTX_SD2: J2.13 (SDI2); also elsewhere on the board
/HSTX_SD3: J2.15 (SDI3); also elsewhere on the board
/VSYS_IN: JP6.3 (B); also elsewhere on the board
/screen-headers/DCX_RS: J2.3 (DCX_RS), R6.2, TP2.1
/screen-headers/IM0: J2.19 (IM0), JP4.2 (C)
/screen-headers/IM1: J2.17 (IM1), JP5.2 (C)
/screen-headers/PWR_EN: J2.22 (PWR_EN), JP7.2 (C)
/screen-headers/SCREEN_VBAT: C8.1, C9.1, J2.18 (VBAT), J2.20 (VBAT), JP6.2 (C)
/~SCREEN_CSB: J2.11 (CS); also elsewhere on the board
/~SCREEN_RST: J2.1 (RESET); also elsewhere on the board
GND: C7.2, C8.2, C9.2, J2.4 (GND), J2.21 (GND), J2.23 (MIPI_CLKP), J2.25 (MIPI_CLKN), J2.27 (GND), J2.28 (GND), J2.29 (MIPI_D0P), J2.31 (MIPI_D0N), J2.33 (GND), J3.1, J3.3, J3.5, J3.7, J3.9, J3.11, J3.13, JP4.1 (A), JP5.3 (B), JP7.1 (A), R6.1; also elsewhere on the board

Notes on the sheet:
Screen Pin Header
No TP because MCU doesn't have enough pins and we won't use it in the final version since screen will be behind a lens
00 = SPI 3-wire 01 = SPI 4-wire 10 = QSPI
Needs to be 12.0mm from edge of board, odds side facing edge



Board: 4 copper layers, 75.0 x 75.0 mm, 69 parts (13 on the bottom side), 57 nets.

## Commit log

2024-08-31 initial commit - carrier
    [battery-bq25628e.kicad_sch, pico2-carrier.kicad_pcb, pico2-carrier.kicad_sch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]
2024-08-31 start work on PCB
    [battery-bq25628e.kicad_sch, pico2-carrier.kicad_pcb, pico2-carrier.kicad_sch]
2024-09-01 finish routing - DRC ok
    [pico2-carrier.kicad_pcb, pico2-carrier.kicad_sch, screen-headers.kicad_sch]
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2024-09-01 add PFET to VSYS input
    [battery-bq25628e.kicad_sch, pico2-carrier.kicad_pcb, pico2-carrier.kicad_sch]
2024-09-07 carrier: remove pcb design to start again
    [pico2-carrier.kicad_pcb]
2024-09-07 carrier: new pcb degisn for better screen placement
    [pico2-carrier.kicad_pcb, pico2-carrier.kicad_sch, screen-headers.kicad_sch]
2024-09-14 carrier: add helper drawings to pcb
    [pico2-carrier.kicad_pcb]
2024-09-15 carrier: add some test points and default jumper connections
    [battery-bq25628e.kicad_sch, pico2-carrier.kicad_pcb, screen-headers.kicad_sch]
2024-09-15 carrier: small pcb updates
    [pico2-carrier.kicad_pcb]
2024-09-15 carrier: add hardware button debounce
    [buttons-debounce.kicad_sch, pico2-carrier.kicad_sch, screen-headers.kicad_sch]
2024-09-21 carrier: add 3.3V zone, start tidying buttons, update caps to 0603
    [battery-bq25628e.kicad_sch, buttons-debounce.kicad_sch, pico2-carrier.kicad_pcb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]
2024-09-21 carrier: update PMIC layout and button filters
    [battery-bq25628e.kicad_sch, pico2-carrier.kicad_pcb]
2024-09-21 carrier: add notes on capacitors
    [battery-bq25628e.kicad_sch]
2024-09-29 carrier: update ir footprint
    [battery-bq25628e.kicad_sch, pico2-carrier.kicad_pcb, pico2-carrier.kicad_sch]
2024-09-29 carrier: move thermistor to back of board and clear space for battery
    [pico2-carrier.kicad_pcb]
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2024-12-01 carrier: add some improvements to eeprom
    [pico2-carrier.kicad_sch]
2025-02-08 rp2350: add start of rp2350 version
    [accel.kicad_sch, buttons.kicad_sch, connectors.kicad_sch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]
2025-03-15 v0.2: add initial schematic files
    [accel_bma400.kicad_sch, buttons_debounce.kicad_sch, connectors.kicad_sch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]
2025-03-22 v0.2: first draft of schematic and footprints
    [rp2350-v0.2.kicad_sch]
2025-03-22 v0.2: schematic draft 1 done
    [accel_bma400.kicad_sch, connectors.kicad_sch, eeprom_m95512.kicad_sch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]
2025-03-22 v0.2: good start on pcb layout
    [rp2350-v0.2.kicad_pcb]
2025-03-23 v0.2: loads of progress now gonna change it all up again
    [mcu_rp2350a.kicad_sch, rp2350-v0.2.kicad_pcb]
2025-03-24 v0.2: more progress on routing, nearly done
    [buttons_debounce.kicad_sch, connectors.kicad_sch, mcu_rp2350a.kicad_sch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]
2025-03-26 v0.2: routing done, nearly ready for prod
    [bom.csv, designators.csv, mcu_rp2350a.kicad_sch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]
2025-03-28 v0.2: final big checks done, fixed IrDA footprint
    [connectors.kicad_sch, irda_pio.kicad_sch, mcu_rp2350a.kicad_sch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]
2025-03-28 v0.2: update battery connector and labels
    [connectors.kicad_sch, power_smps.kicad_sch, rp2350-v0.2.kicad_pcb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]
2025-03-28 v0.2: minor position adjustments
    [rp2350-v0.2.kicad_pcb]
2025-03-29 v0.2: sent to jlc
    [mcu_rp2350a.kicad_sch, rp2350-v0.2.kicad_pcb, screen_dw0180fmst08.kicad_sch]
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2025-06-01 v0.2: add start of v0.3
    [accel_bma400.kicad_sch, buttons_debounce.kicad_sch, connectors.kicad_sch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]
2025-06-07 v0.3: lots of routing done
    [accel_bma400.kicad_sch, buttons_debounce.kicad_sch, eeprom_m95512.kicad_sch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]
2025-06-07 v0.3: move pmic to right side of board
    [flash_w25q1282.kicad_sch, v0.3.kicad_pcb, v0.3.kicad_sch]
2025-06-08 v0.3: DRC checks mostly pass, onto final tweaks
    [connectors.kicad_sch, mcu_rp2350a.kicad_sch, power_smps.kicad_sch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]
2025-06-08 v0.3: update todo a bit
    [connectors.kicad_sch]
2025-07-06 v0.3: moved everything down a bit to better fit voltage reg
    [v0.3.kicad_pcb]
2025-07-13 v0.3: small tweaks and added panel tabs
    [v0.3.kicad_pcb]
2025-08-01 v0.3: sent to fab
    [irda_pio.kicad_sch, v0.3.kicad_pcb]
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2025-10-12 v0.2: move files around
    [accel.kicad_sch, accel_bma400.kicad_sch, bom.csv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]
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2025-10-12 v0.4: add start files for v0.4
    [accel_bma400.kicad_sch, buttons.kicad_sch, connectors.kicad_sch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]
2025-10-12 v0.4: schematic laid out first draft
    [accel_bma400.kicad_sch, buttons.kicad_sch, connectors.kicad_sch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]
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2025-11-09 v0.4: first rough placement of PCB
    [Picowalker32_Outline.dxf, Picowalker32_RearKeepout.dxf, accel_bma400.kicad_sch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]
2025-12-17 v0.4: good start on routing
    [accel_bma400.kicad_sch, buttons.kicad_sch, connectors.kicad_sch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]
2025-12-18 v0.4: running DRC checks
    [connectors.kicad_sch, picowalker-v0.4.kicad_pcb, picowalker-v0.4.kicad_sch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]
2025-12-19 v0.4: drc mostly done, need to fiddle with TH1
    [accel_bma400.kicad_sch, buttons.kicad_sch, connectors.kicad_sch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]
2025-12-19 v0.4: update readme and add renders
    [connectors.kicad_sch, picowalker-v0.4.kicad_pcb]
2025-12-22 v0.4: add more step files
    [picowalker-v0.4.kicad_pcb]
2025-12-22 v0.4: update usb and rpi inductor models
    [picowalker-v0.4.kicad_pcb]
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2026-06-27 v0.4: connect i2c to TP and add silkscreen labels
    [accel_bma400.kicad_sch, buttons.kicad_sch, connectors.kicad_sch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]
2026-06-28 misc: update pad clearance on mezzanine connector
